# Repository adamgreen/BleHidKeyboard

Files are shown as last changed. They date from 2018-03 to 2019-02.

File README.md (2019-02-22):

# BLE HID Keyboard
A project to convert a [Perixx PERIDUO-307B USB wired keyboard](https://www.amazon.com/Perixx-PERIBOARD-407B-Mini-Keyboard-Dimension/dp/B0053O9ZNQ/) to wireless Bluetooth Low Energy (BLE). The conversion is accomplished by replacing the original PCB with the one documented here which uses a [Nordic nRF51422](https://www.nordicsemi.com/eng/Products/ANT/nRF51422) BLE capable ARM Cortex-M0 microcontroller. This repository includes the Eagle CAD PCB design files and firmware source code.

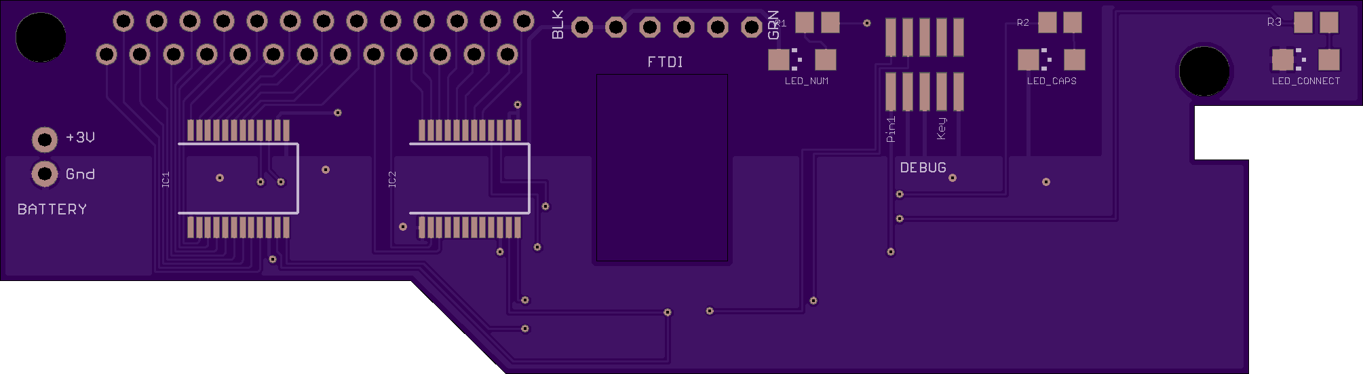
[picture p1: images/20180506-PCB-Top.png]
OSHPark rendering of PCB Top


## Bill of Materials
Description | Quantity | Part Number(s)
------------|----------|---------------
[Perixx PERIDUO-307B USB wired keyboard](https://www.amazon.com/Perixx-PERIBOARD-407B-Mini-Keyboard-Dimension/dp/B0053O9ZNQ/) | 1 |
[SODIAL 3W LED Mini Pen Torch Flashlight 2xAAA](https://www.amazon.com/gp/product/B01J58ZHOG) | 1 |
[1.2kΩ Resistor - 0805](https://www.adafruit.com/product/441) | 3 | R1, R2, R3
[Microchip MCP23018 I2C I/O Expander](https://www.digikey.com/product-detail/en/microchip-technology/MCP23018-E-SS/MCP23018-E-SS-ND/1999506) | 2 | IC1, IC2
[Samtec 2x5 SMT Micro Header](https://www.digikey.com/product-detail/en/FTSH-105-01-L-DV-K/SAM8799-ND/1875039) | 1 | JP1
[Dynastream N5150M5CD - nRF51422 Module](https://www.digikey.com/products/en?keywords=N5150M5CD) | 1 | U1
[Green SMT LED](https://www.digikey.com/product-detail/en/kingbright/APTD3216LCGCK/754-2049-1-ND/7043101) | 3 | LED_CAPS, LED_CONNECT, LED_NUM LED

It also requires a 2x13 ribbon cable connector harvested from the original PCB using a [Chip Quick SMD Removal Kit](https://www.adafruit.com/product/2660).

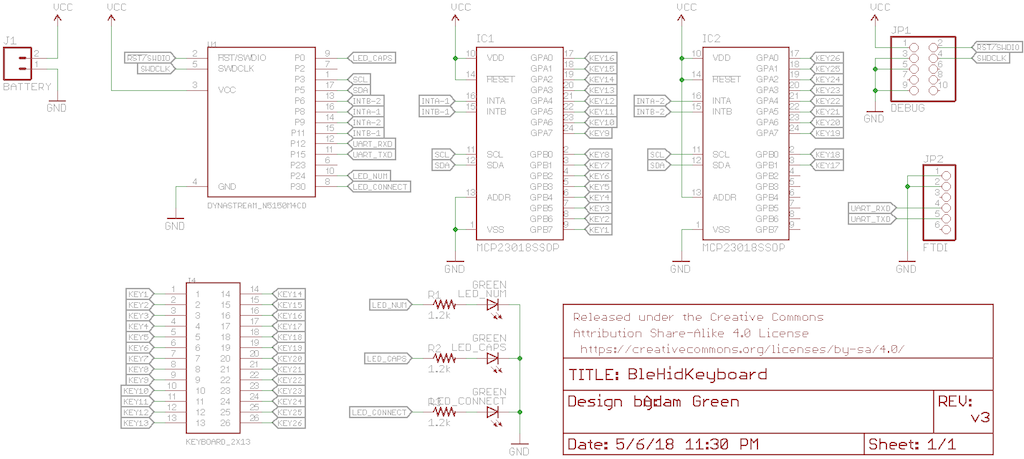
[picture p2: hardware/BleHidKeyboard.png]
Schematic


## Firmware Build
I have only tested the build on macOS but it will probably work on other Posix operating systems too.

**Note:** Building the firmware and deploying it to the nRF51 requires the **mergehex** and **nrfjprog** tools. The archive for your OS can be downloaded from the _Downloads_ tab of the [nRF51422 product page](https://www.nordicsemi.com/eng/Products/Bluetooth-low-energy/nRF51422). You will also need a SEGGER J-Link JTAG/SWD Debugger. If your projects are of a non-commercial nature, you can use this [low cost module available from Adafruit](https://www.adafruit.com/product/3571).

* ```make sdk``` will download and install the required Nordic SDK. This should only need to be done once.
* ```make flash_softdevice``` will install the required Nordic SoftDevice on the nRF51422 microcontroller using the J-Link debugger. This will typically only need to be done once for each microcontroller.
* ```make all``` will build the keyboard firmware.
* ```make flash```will build the keyboard firmware and deploy it using the J-Link debugger.
* ```make generate_patches``` can be used to generate diffs for any files that you have modified in the [config/ subfolder](https://github.com/adamgreen/BleHidKeyboard/tree/master/firmware/config) so that you can commit and share them via git.

## Photos
**Perixx PERIDUO-307B USB Wired Keyboard**<br>
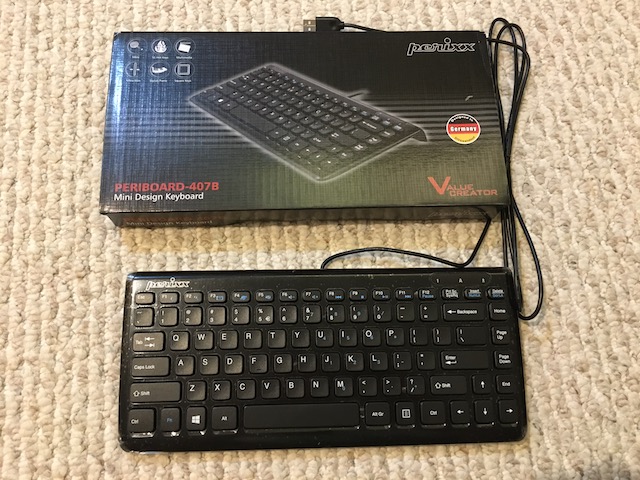
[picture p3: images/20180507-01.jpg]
Keyboard
<br>

**Inside of Keyboard with Original PCB**<br>
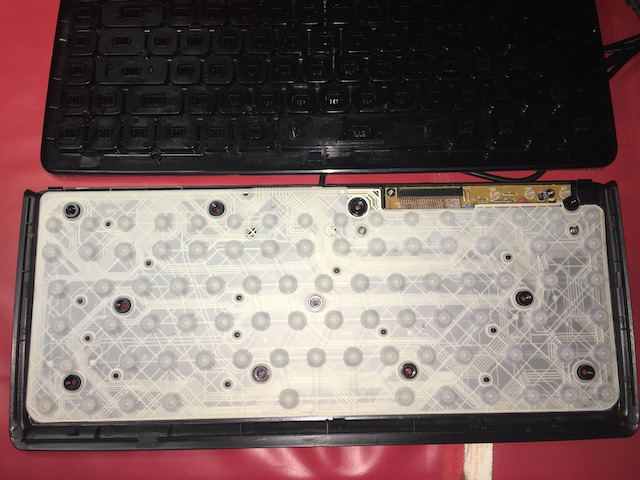
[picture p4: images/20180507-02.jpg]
Original PCB
<br>

**Inside of Keyboard with New BLE PCB**<br>
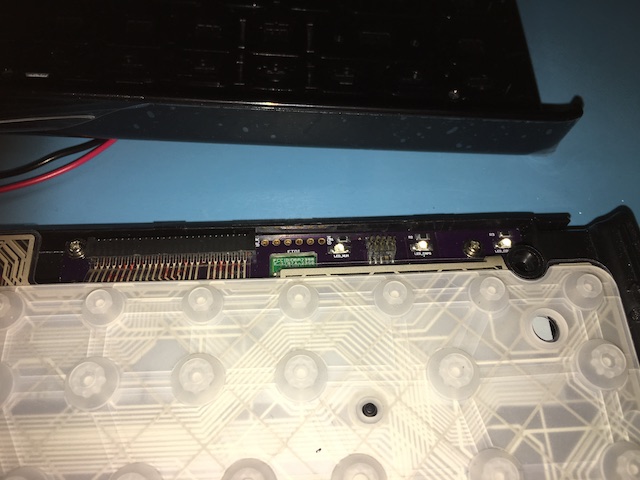
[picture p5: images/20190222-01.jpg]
New PCB From Top
<br>

**Peeking Under Membrane at New BLE PCB**<br>
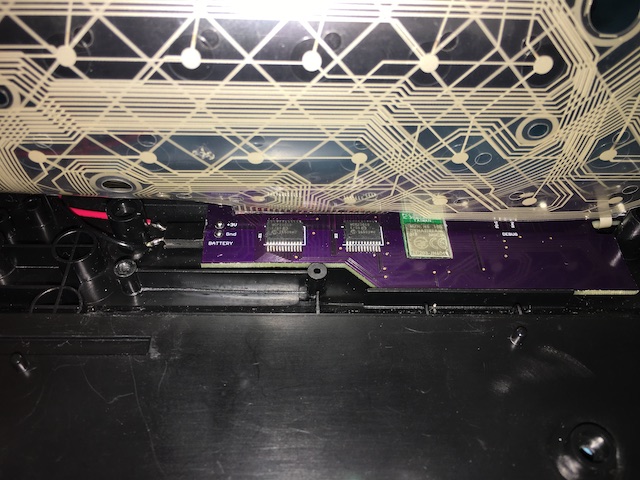
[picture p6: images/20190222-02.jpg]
New PCB Looking Under Membrane
<br>

**Inside of Keyboard After Modifications**<br>
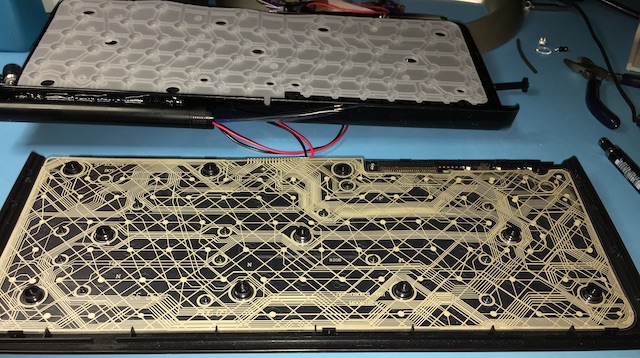
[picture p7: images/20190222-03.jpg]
Inside of Keyboard
<br>

**Keyboard with 2xAAA Torchlight as Battery Pack**<br>
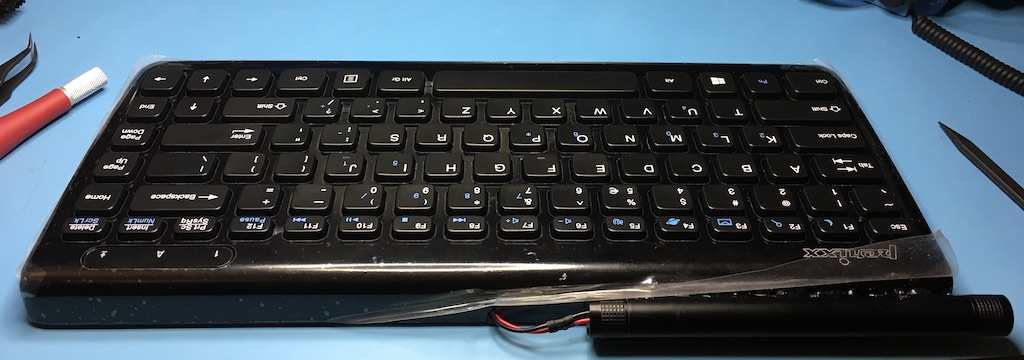
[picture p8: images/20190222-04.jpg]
Full Keyboard
<br>

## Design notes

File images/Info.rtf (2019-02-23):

Sleep: <Fn> + <F1>
Wakeup: <Space>
Forget Devices: Press <Delete> during power on

Scroll Lock LED
Blinking: Waiting to connect to device
Solid: Connected to device
Off: Sleeping or powered off

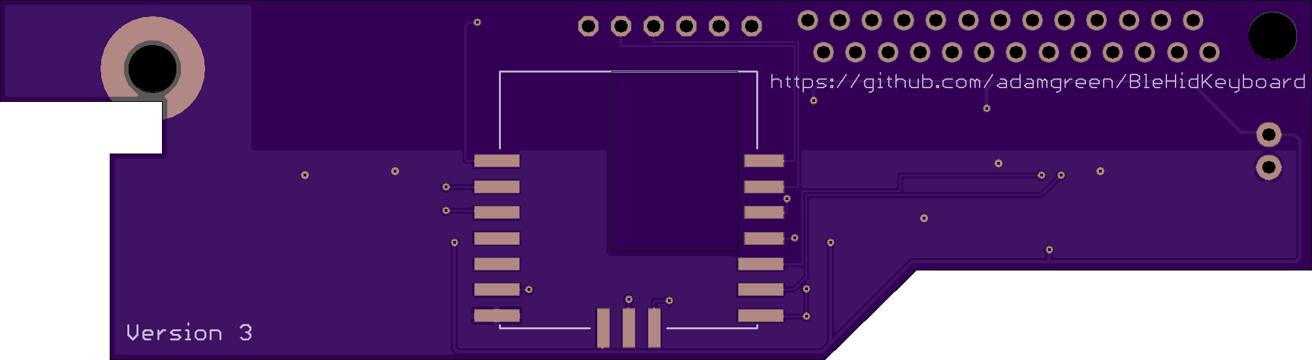
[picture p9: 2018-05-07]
images/20180506-PCB-Bottom.png

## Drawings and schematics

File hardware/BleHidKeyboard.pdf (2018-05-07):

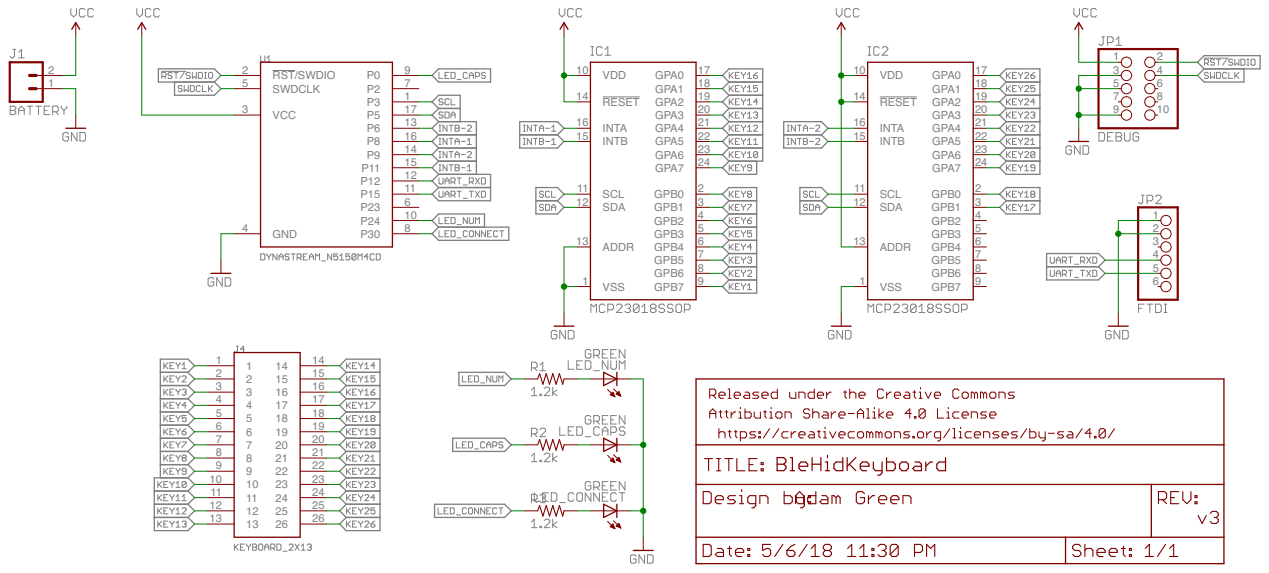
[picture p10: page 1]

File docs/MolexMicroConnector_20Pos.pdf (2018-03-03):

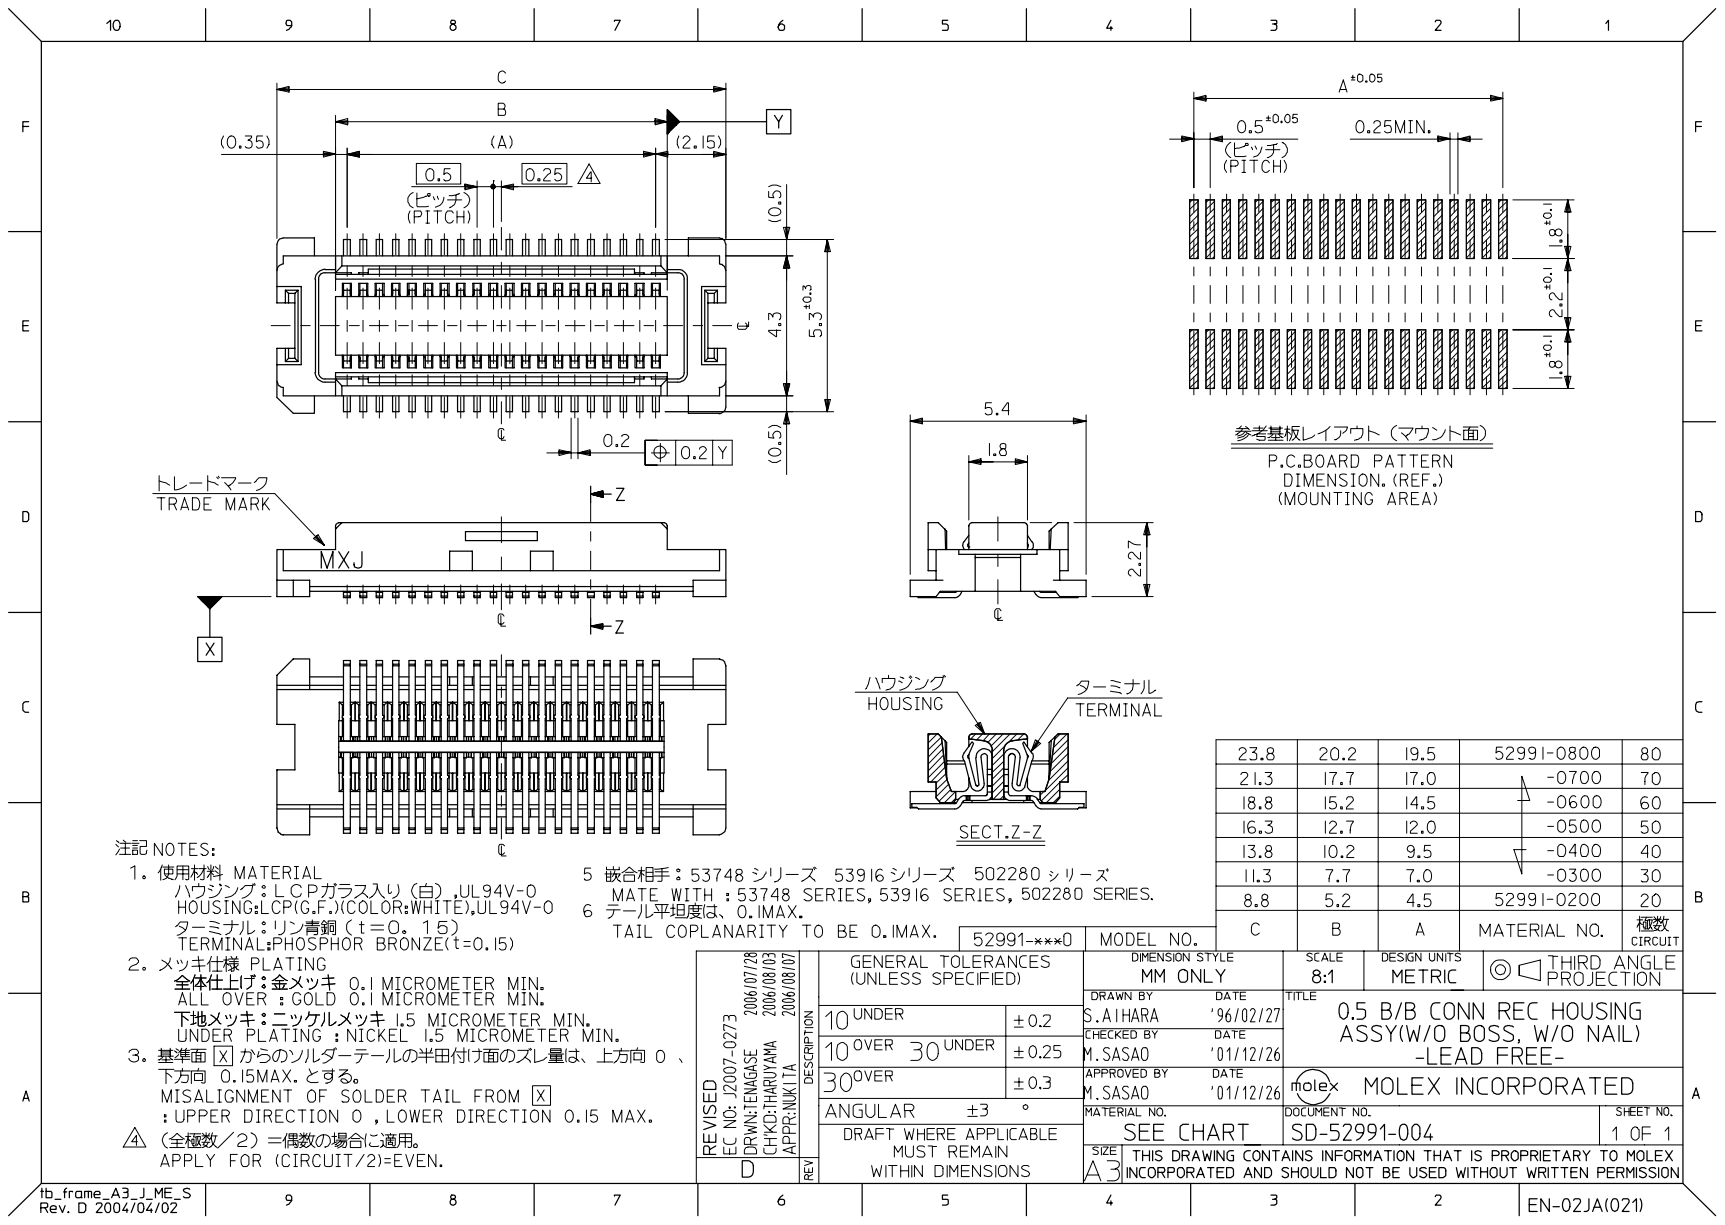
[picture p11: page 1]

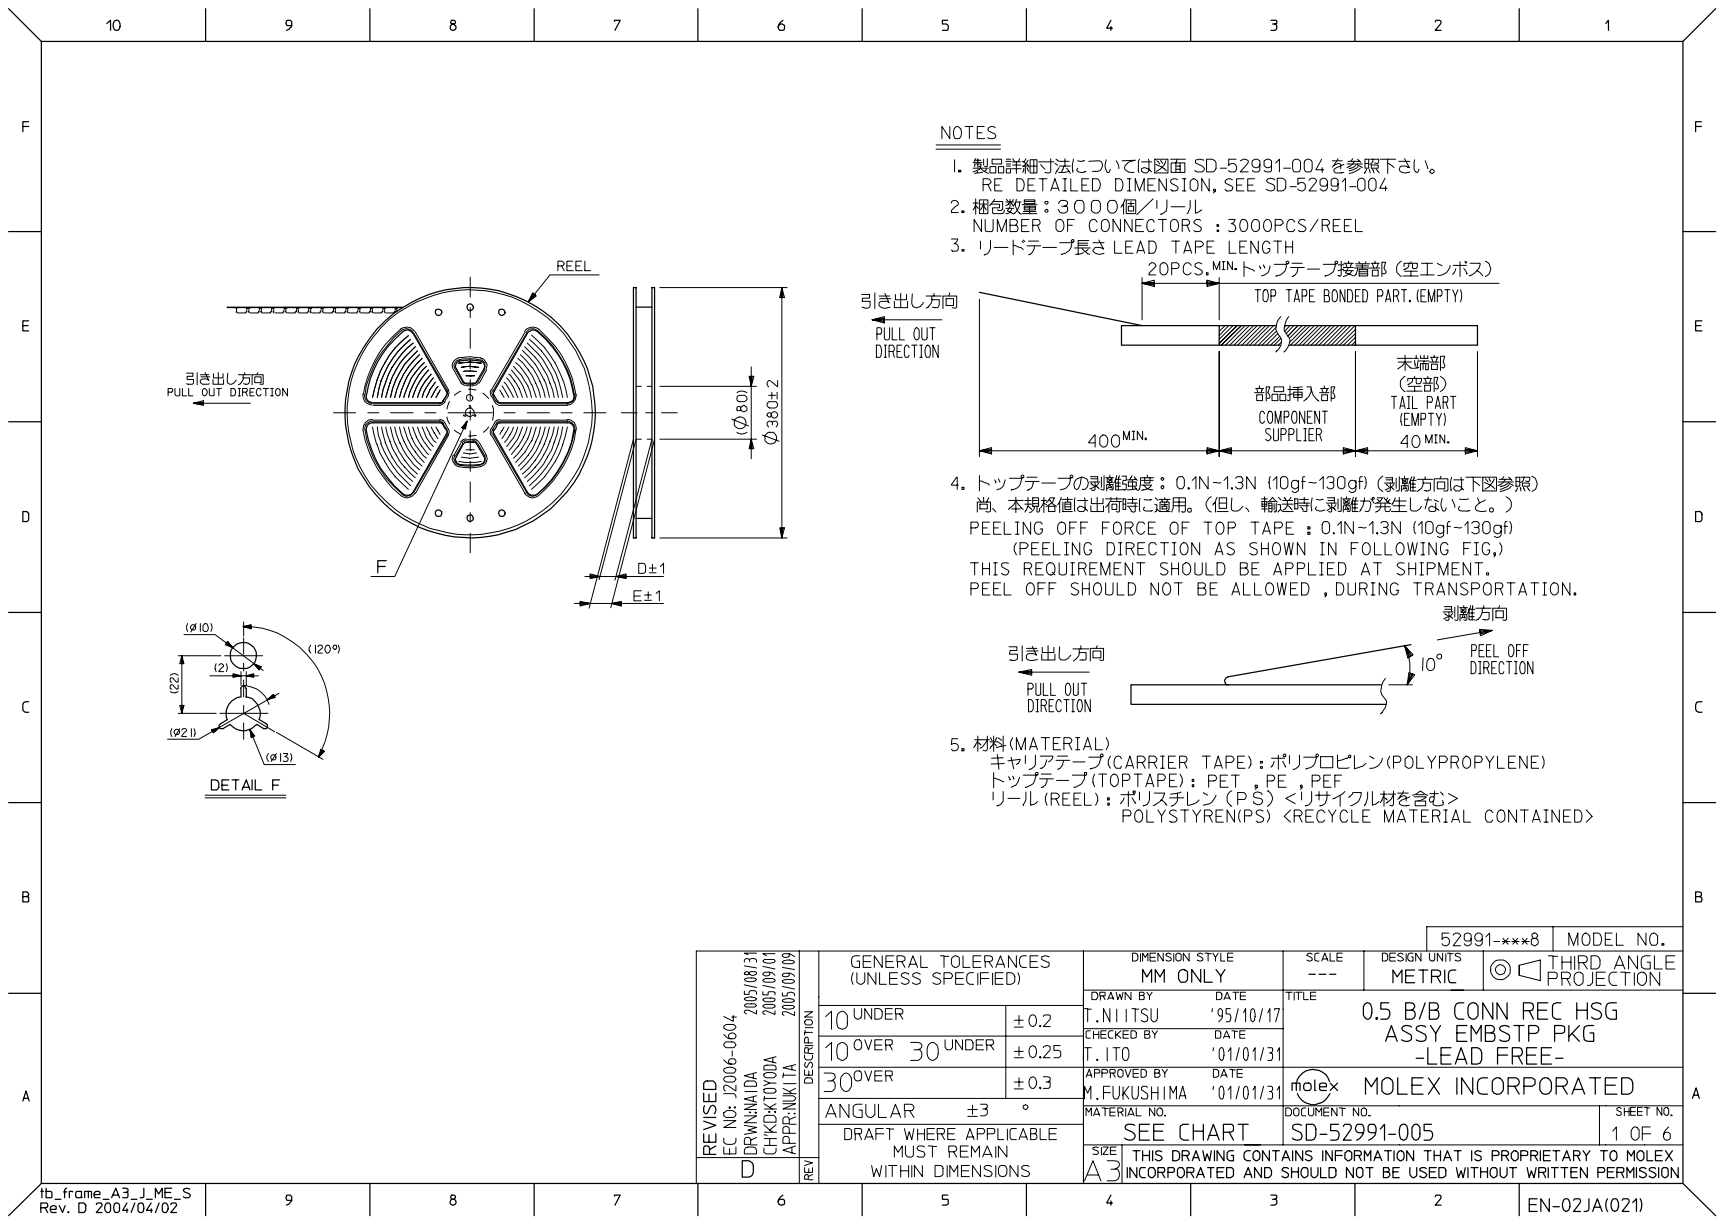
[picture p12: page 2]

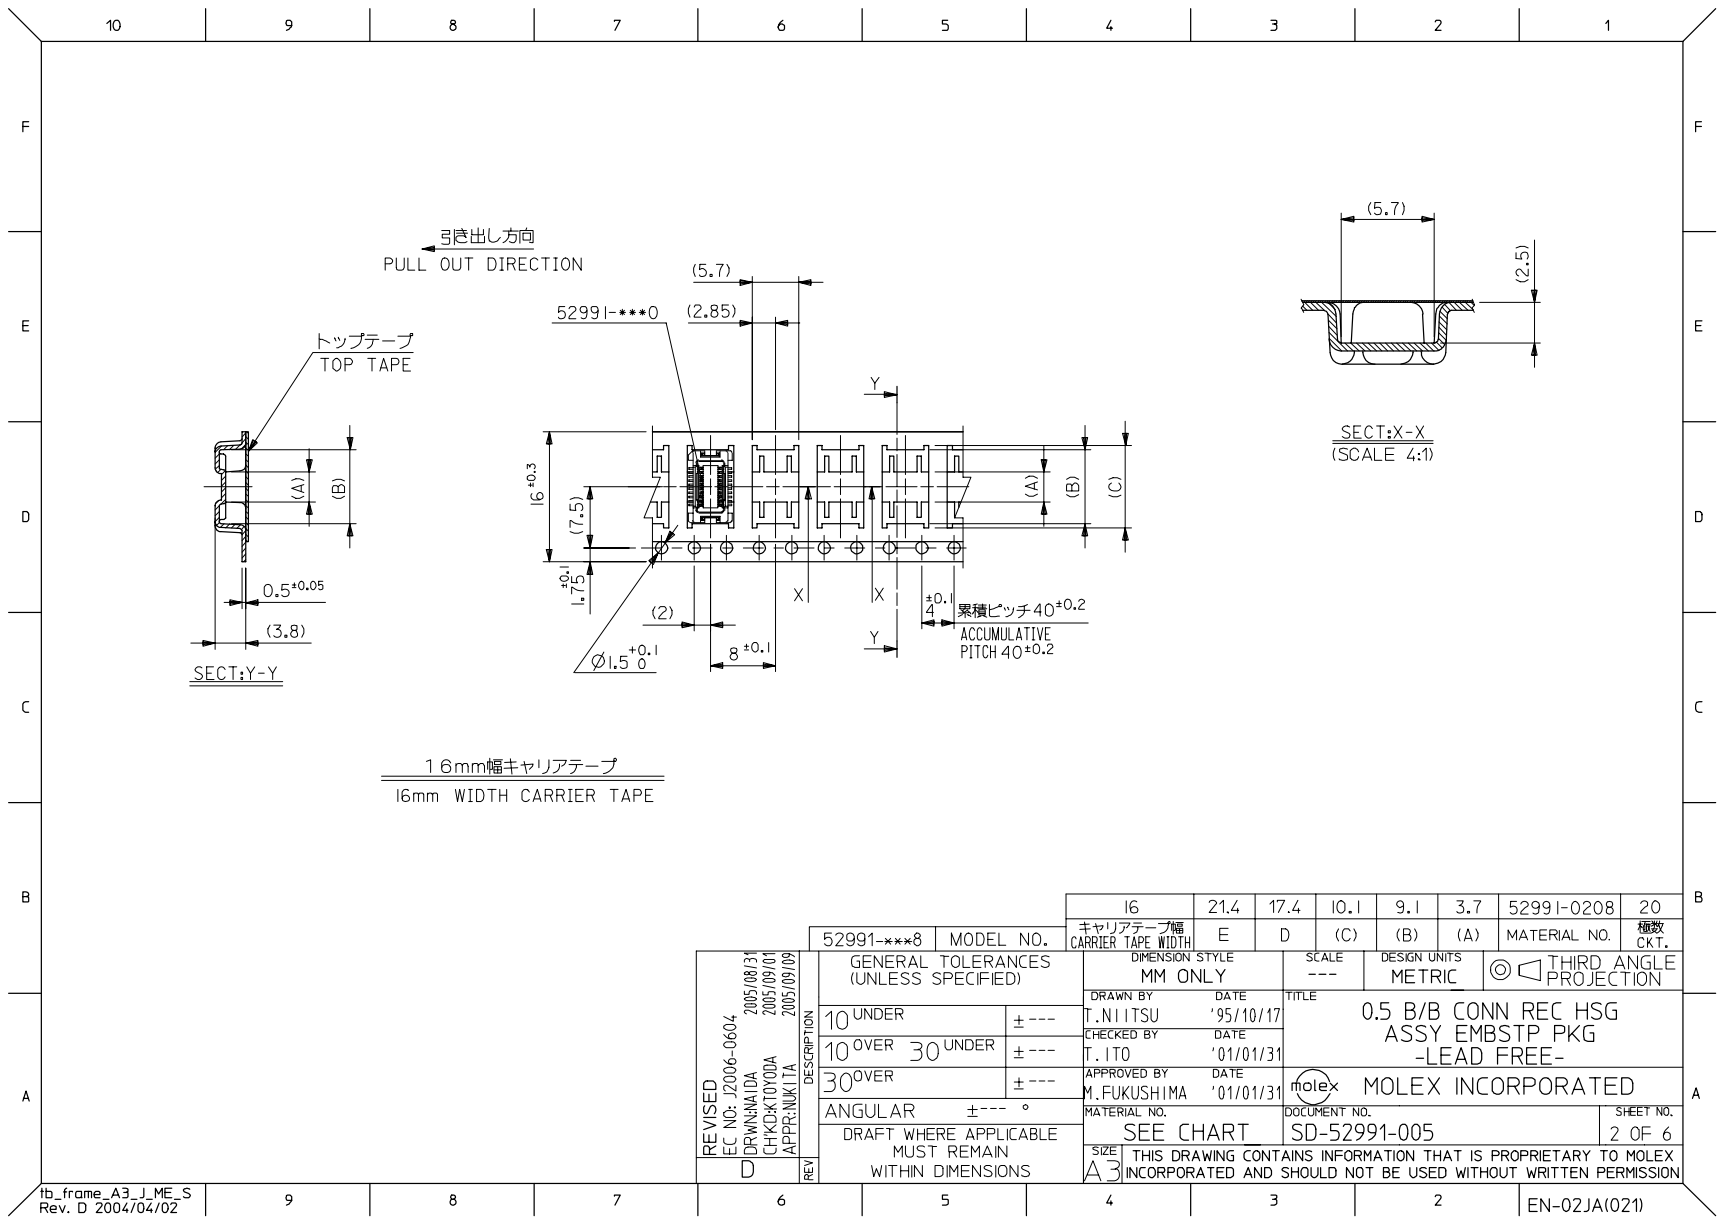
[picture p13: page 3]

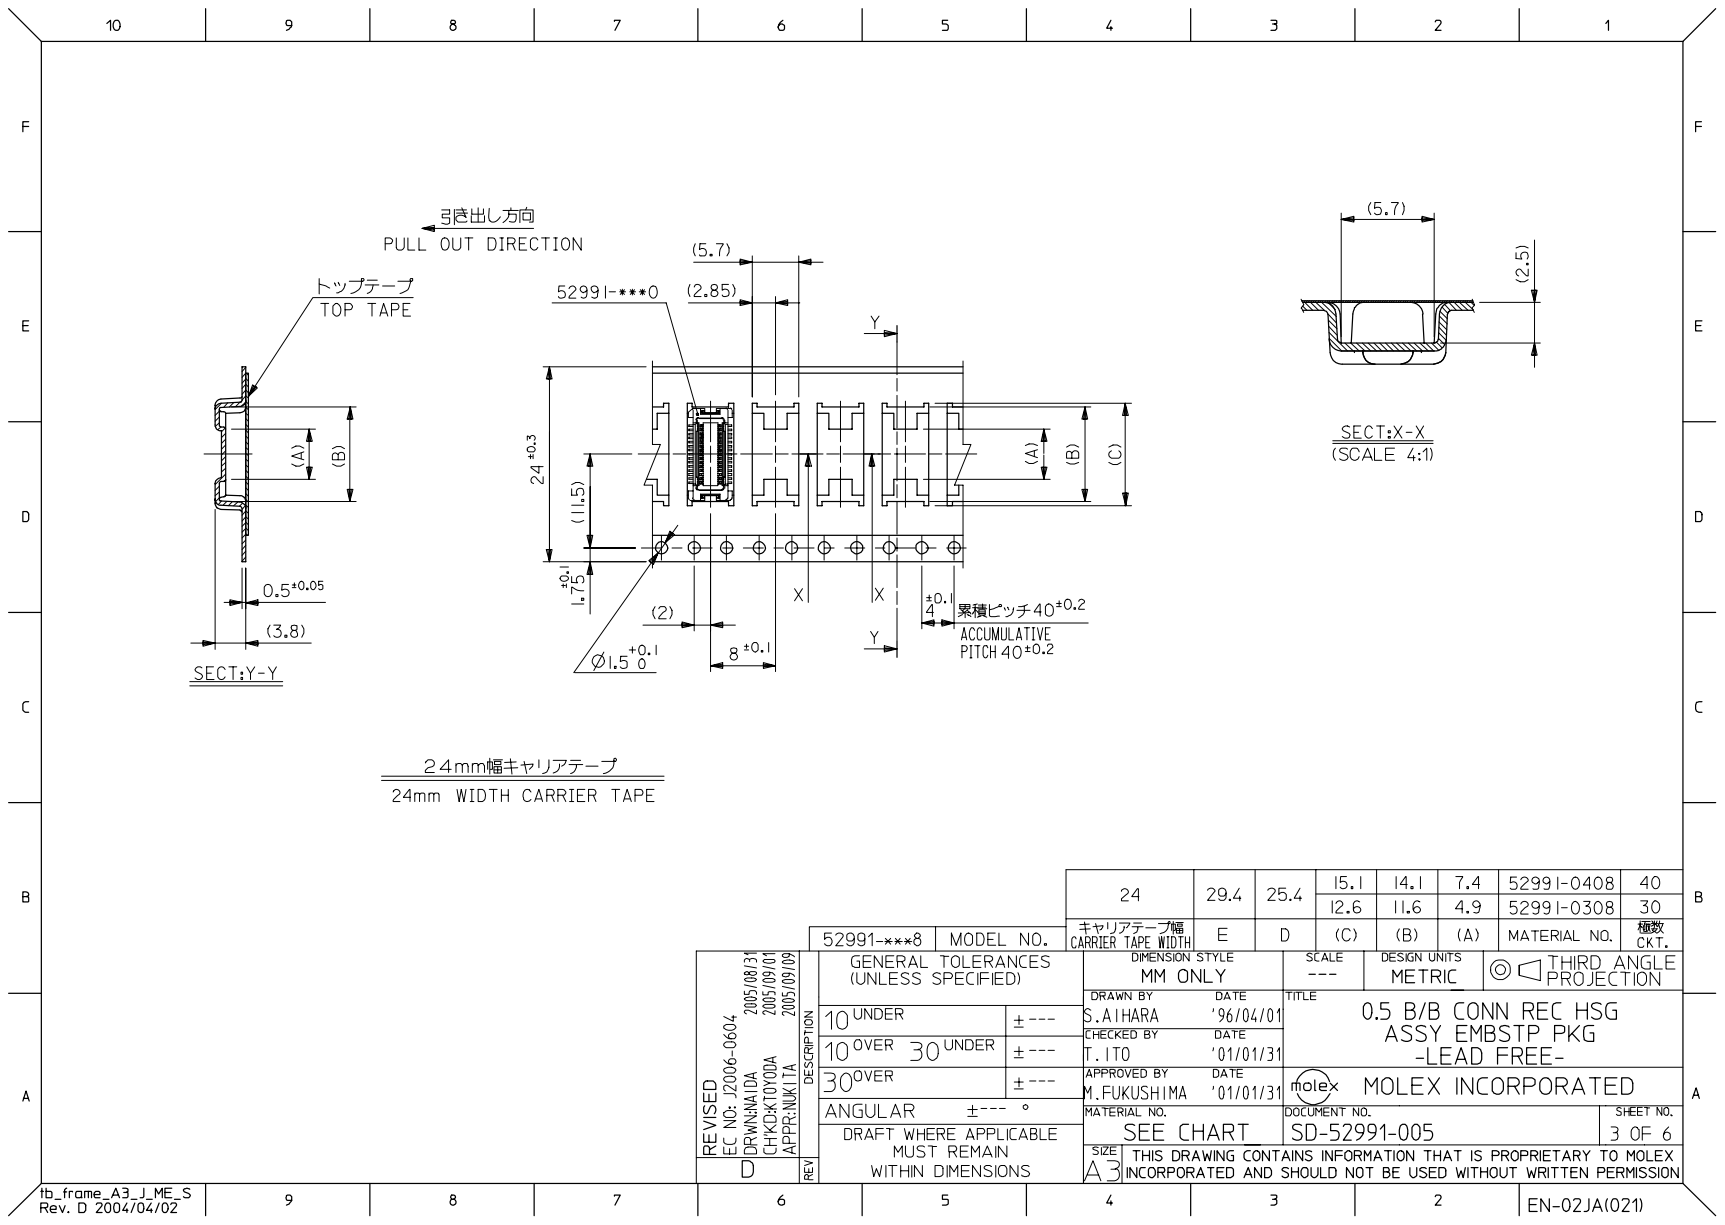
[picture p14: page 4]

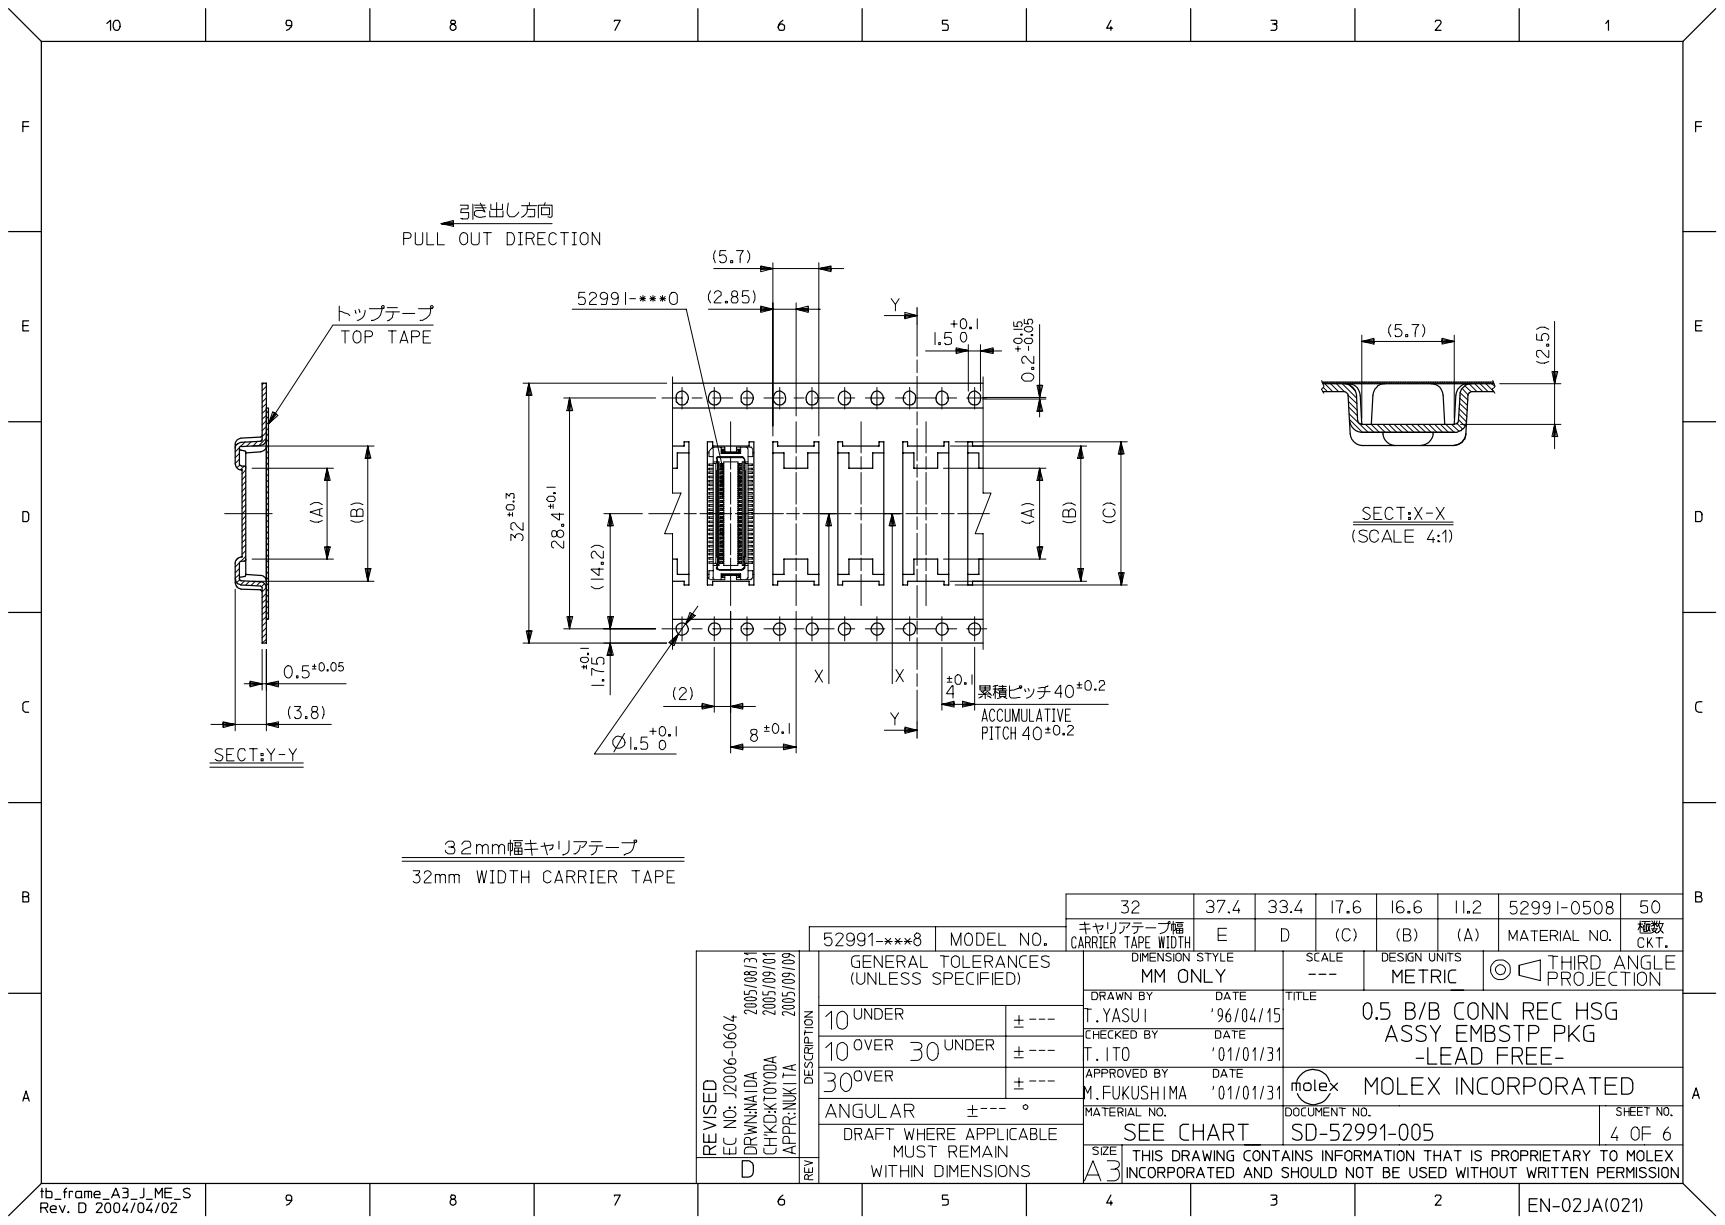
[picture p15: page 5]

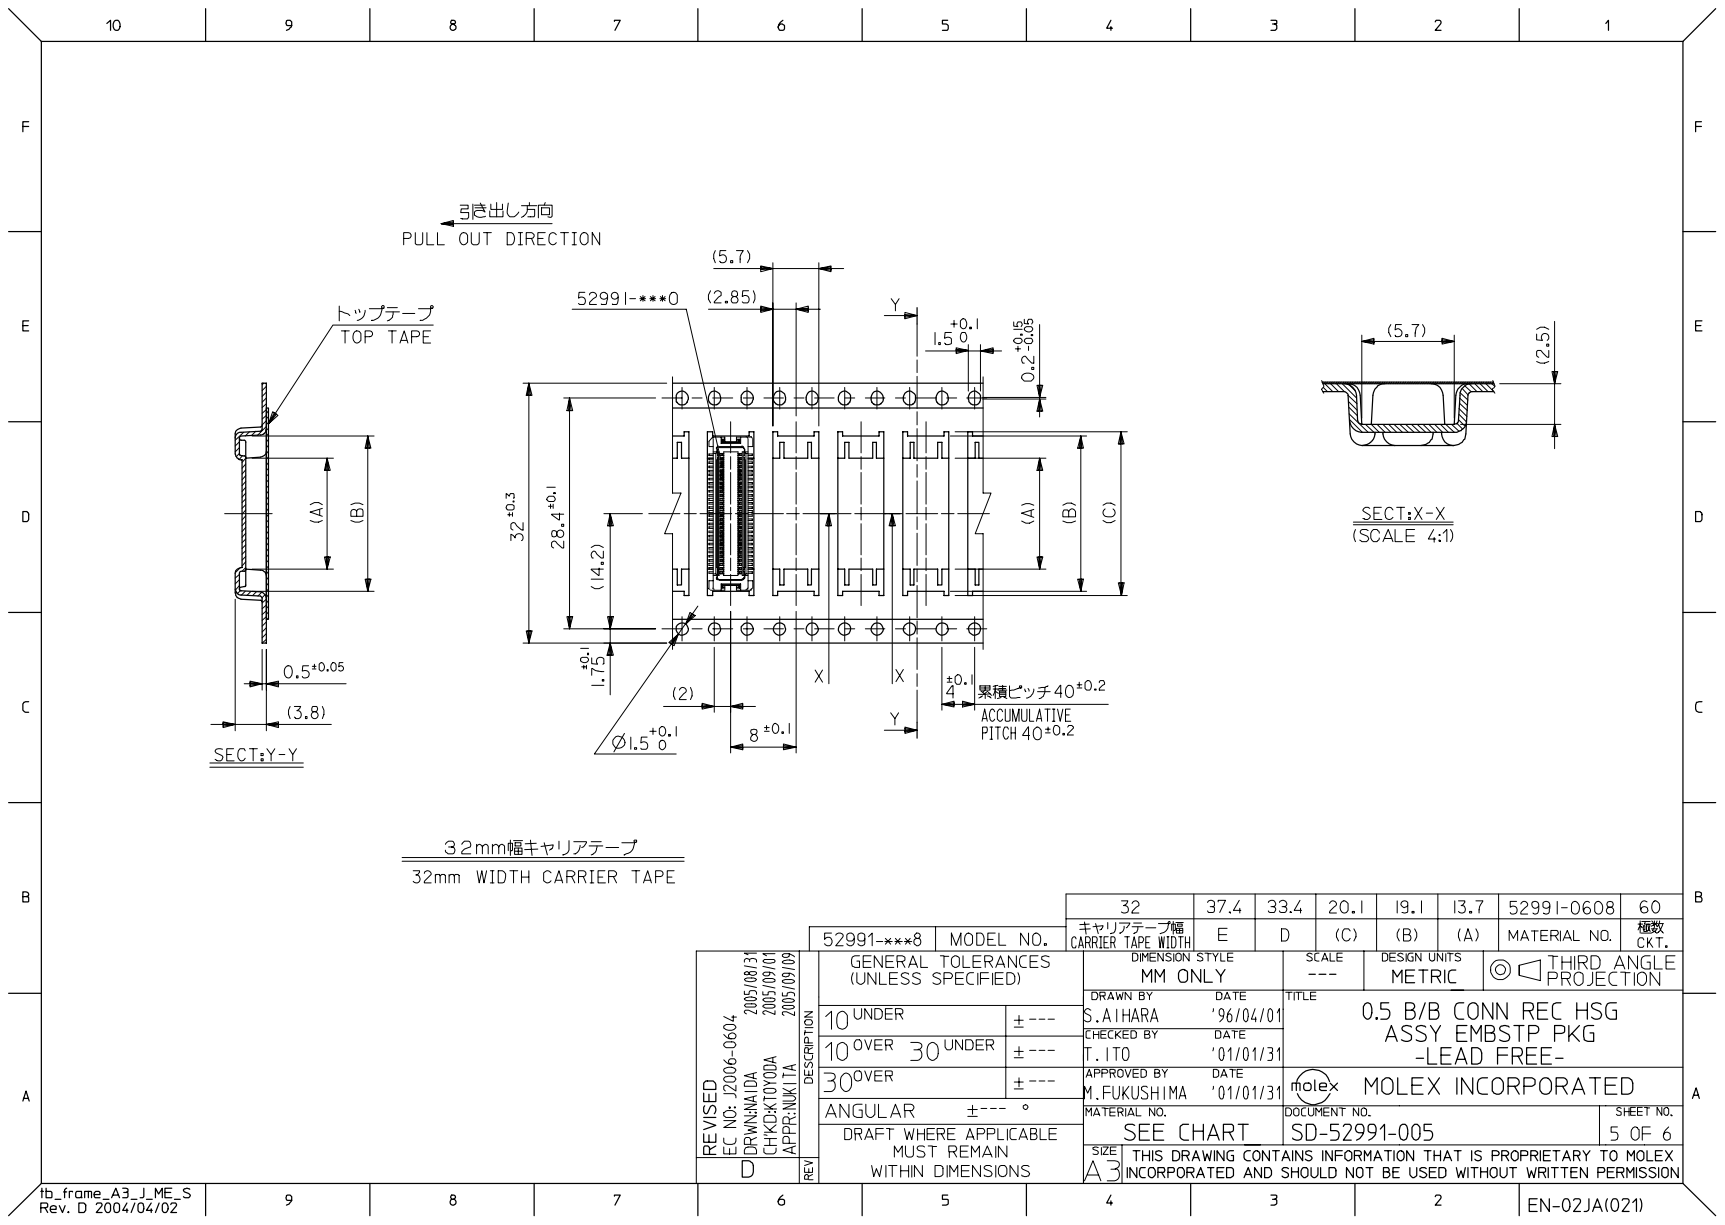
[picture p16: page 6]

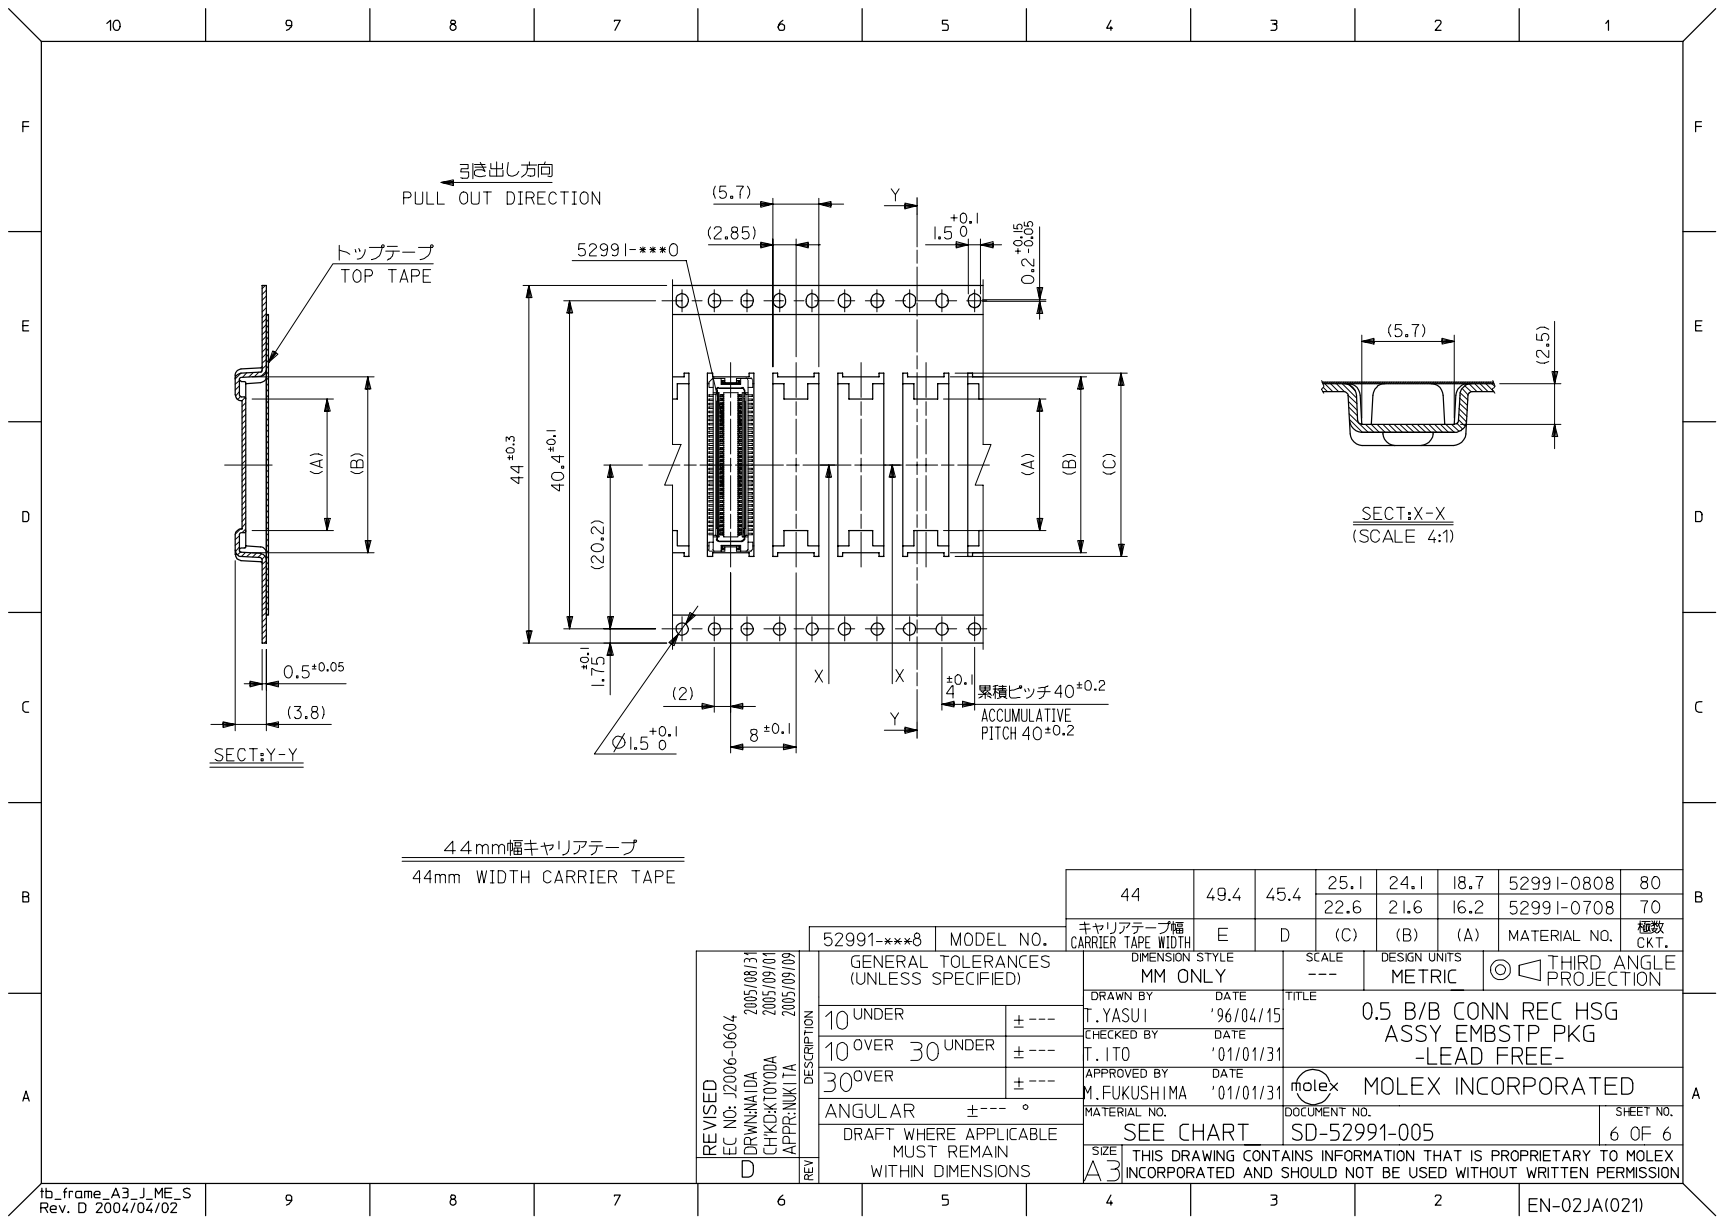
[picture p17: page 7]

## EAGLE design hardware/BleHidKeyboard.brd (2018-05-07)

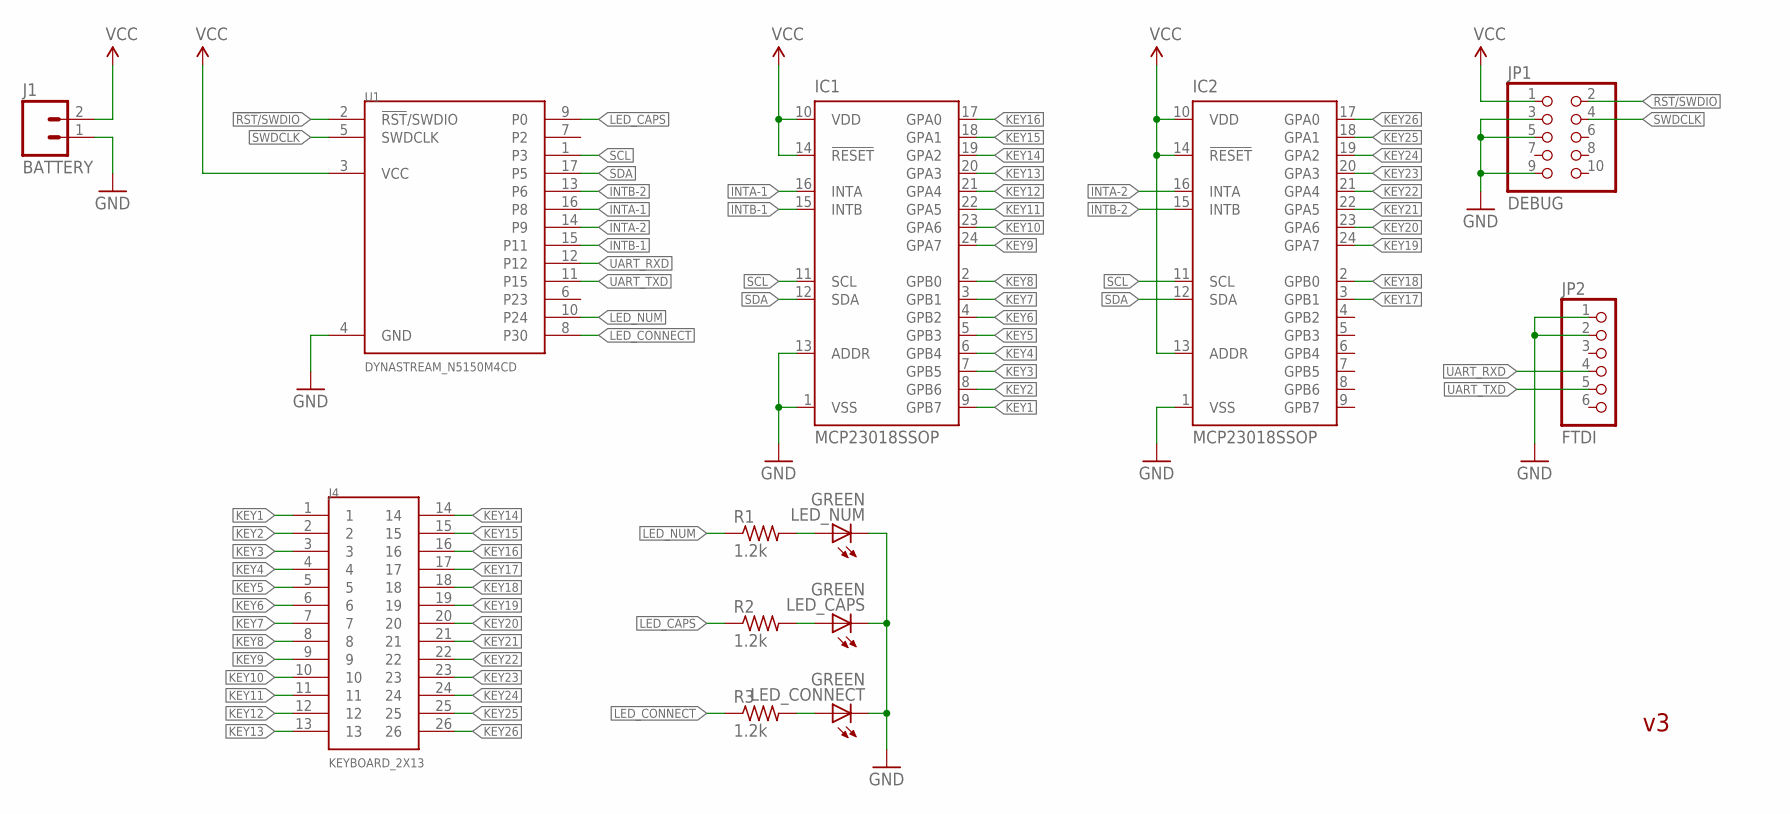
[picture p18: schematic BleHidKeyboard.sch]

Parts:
IC1, IC2: MCP23018SSOP; SSOP24
J1: BATTERY; 1X02_NO_SILK
J4: KEYBOARD_2X13
JP1: DEBUG; FTSH-105
JP2: FTDI; 1X06-CLEAN
LED_CAPS: GREEN; CHIPLED_1206
LED_CONNECT: GREEN; CHIPLED_1206
LED_NUM: GREEN; CHIPLED_1206
R1, R2, R3: 1.2k; R0805
U1: DYNASTREAM_N5150M4CD; N5150M4CD

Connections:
!RST/!SWDIO: JP1.2, U1.2 (!RST!/SWDIO)
GND: IC1.1 (VSS), IC1.13 (ADDR), IC2.1 (VSS), J1.1, JP1.3, JP1.5, JP1.9, JP2.1, JP2.2, LED_CAPS.C, LED_CONNECT.C, LED_NUM.C, U1.4 (GND)
INTA-1: IC1.16 (INTA), U1.16 (P8)
INTA-2: IC2.16 (INTA), U1.14 (P9)
INTB-1: IC1.15 (INTB), U1.15 (P11)
INTB-2: IC2.15 (INTB), U1.13 (P6)
KEY1: IC1.9 (GPB7), J4.1
KEY2: IC1.8 (GPB6), J4.2
KEY3: IC1.7 (GPB5), J4.3
KEY4: IC1.6 (GPB4), J4.4
KEY5: IC1.5 (GPB3), J4.5
KEY6: IC1.4 (GPB2), J4.6
KEY7: IC1.3 (GPB1), J4.7
KEY8: IC1.2 (GPB0), J4.8
KEY9: IC1.24 (GPA7), J4.9
KEY10: IC1.23 (GPA6), J4.10
KEY11: IC1.22 (GPA5), J4.11
KEY12: IC1.21 (GPA4), J4.12
KEY13: IC1.20 (GPA3), J4.13
KEY14: IC1.19 (GPA2), J4.14
KEY15: IC1.18 (GPA1), J4.15
KEY16: IC1.17 (GPA0), J4.16
KEY17: IC2.3 (GPB1), J4.17
KEY18: IC2.2 (GPB0), J4.18
KEY19: IC2.24 (GPA7), J4.19
KEY20: IC2.23 (GPA6), J4.20
KEY21: IC2.22 (GPA5), J4.21
KEY22: IC2.21 (GPA4), J4.22
KEY23: IC2.20 (GPA3), J4.23
KEY24: IC2.19 (GPA2), J4.24
KEY25: IC2.18 (GPA1), J4.25
KEY26: IC2.17 (GPA0), J4.26
LED_CAPS: R2.1, U1.9 (P0)
LED_CONNECT: R3.1, U1.8 (P30)
LED_NUM: R1.1, U1.10 (P24)
unnamed: LED_NUM.A, R1.2
unnamed: LED_CAPS.A, R2.2
unnamed: LED_CONNECT.A, R3.2
SCL: IC1.11 (SCL), IC2.11 (SCL), U1.1 (P3)
SDA: IC1.12 (SDA), IC2.12 (SDA), U1.17 (P5)
SWDCLK: JP1.4, U1.5 (SWDCLK)
UART_RXD: JP2.4, U1.12
UART_TXD: JP2.5, U1.11 (P15)
VCC: IC1.10 (VDD), IC1.14 (!RESET), IC2.10 (VDD), IC2.13 (ADDR), IC2.14 (!RESET), J1.2, JP1.1, U1.3 (VCC)

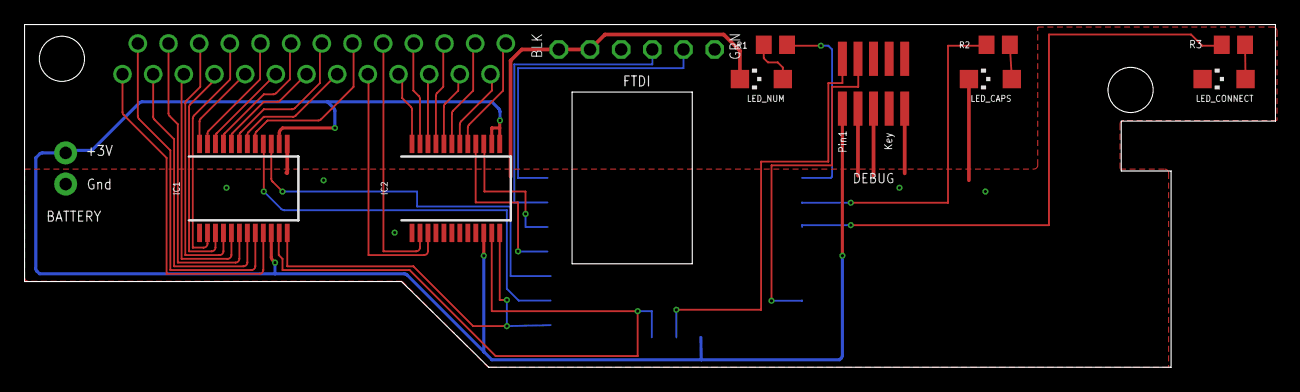
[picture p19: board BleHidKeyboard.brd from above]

Board: 2 copper layers, 102.0 x 27.9 mm, 13 parts (0 on the bottom side), 44 nets.

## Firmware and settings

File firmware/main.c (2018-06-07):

/*  Copyright (C) 2018  Adam Green (https://github.com/adamgreen)

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
    This program is distributed in the hope that it will be useful,
    but WITHOUT ANY WARRANTY; without even the implied warranty of
    MERCHANTABILITY or FITNESS FOR A PARTICULAR PURPOSE.  See the
    GNU General Public License for more details.
*/
/*
    Wireless keyboard firmware.
    This firmware is essentially a combination of 2 main features:
    * Wireless connectivity to PC via Bluetooth Low Energy HID protocol. This allows it to work on iOS devices.
    * Remapping of alpha keys so that they can be arranged in ABC order instead of the usual QWERTY.

    The BLE code in this project originated from Nordic Semiconductor's BLE HID Keyboard Sample.
*/
#include <stdint.h>
#include <string.h>
#include <nordic_common.h>
#include <nrf.h>
#include <nrf_assert.h>
#include <app_error.h>
#include <nrf_gpio.h>
#include <ble.h>
#include <ble_hci.h>
#include <ble_srv_common.h>
#include <ble_advertising.h>
#include <ble_advdata.h>
#include <ble_hids.h>
#include <ble_bas.h>
#include <ble_dis.h>
#include <ble_conn_params.h>
#include <bsp.h>
#include <app_scheduler.h>
#include <softdevice_handler_appsh.h>
#include <app_timer_appsh.h>
#include <device_manager.h>
#include <app_button.h>
#include <pstorage.h>
#include <app_trace.h>
#include <nrf_drv_gpiote.h>
#include <app_uart.h>
#include <nrf_adc.h>
#include "KeyboardMatrix.h"
#include "MCP23018.h"
#include "nrf_drv_timer.h"


// nRF51 pins connected to the I2C pins on the MCP23018 I/O expanders used with the keyboard matrix.
#define KEYBOARD_SCL_PIN                3
#define KEYBOARD_SDA_PIN                5

// The INTA & INTB pins for each of the MCP23018 devices.
#define KEYBOARD_INTA1_PIN              8
#define KEYBOARD_INTB1_PIN              11
#define KEYBOARD_INTA2_PIN              9
#define KEYBOARD_INTB2_PIN              6

// There are two MCP23018 16-bit I/O expanders used to connect to all of the columns and rows of the keyboard matrix.
// The following defines provide the I2C addresss of these two MCP23018 expanders.
#define KEYBOARD_MCP23018_1_I2C_ADDRESS 0x20
#define KEYBOARD_MCP23018_2_I2C_ADDRESS 0x27

// Configuration options for the interrupt driven UART driver.
#define UART_TX_PIN      15
#define UART_RX_PIN      12
// CTS & RTS not actually used in this implementation.
#define UART_CTS_PIN     0xFF
#define UART_RTS_PIN     0xFF
#define UART_TX_BUF_SIZE 256
#define UART_RX_BUF_SIZE 1

// nRF51 pins used for caps and num lock LEDs.
#define CAPS_LOCK_PIN   0
#define NUM_LOCK_PIN    24

// Set to non-zero value to dump BLE HID reports.
#define DEBUG_SHOW_HID_REPORT       0

// Set to non-zero value if we want to remap keyboard to be special alphabetical order keyboard.
#define KEYBOARD_IS_SPECIAL_ABC     1

// BLE HID is based on USB HID. The keyboard communicates with 8-byte input reports and 1-byte output report.
// Version number of base USB HID Specification implemented by this application.
#define BASE_USB_HID_SPEC_VERSION        0x0101
// Index of Output Report.
#define OUTPUT_REPORT_INDEX              0
// Maximum length of Output Report.
#define OUTPUT_REPORT_MAX_LEN            sizeof(HidKeyboardOutputReport)
// Id of reference to Keyboard Output Report.
#define OUTPUT_REP_REF_ID                0
// Index of Input Report.
#define INPUT_REPORT_KEYS_INDEX          0
// Id of reference to Keyboard Input Report.
#define INPUT_REP_REF_ID                 0
// Maximum length of the Input Report characteristic.
#define INPUT_REPORT_KEYS_MAX_LEN        sizeof(HidKeyboardInputReport)


// Include or not the service_changed characteristic. 
// If not enabled, the server's database cannot be changed for the lifetime of the device.
#define IS_SRVC_CHANGED_CHARACT_PRESENT  0                                              

// Name of device. Will be included in the advertising data.
#define DEVICE_NAME                      "Pat's Keyboard"
// Manufacturer. Will be passed to Device Information Service.
#define MANUFACTURER_NAME                "PinkyDevelopment"
// Product/Vendor IDs reported by Device Information Service.
#define PNP_ID_VENDOR_ID_SOURCE          0x02
#define PNP_ID_VENDOR_ID                 0x1915
#define PNP_ID_PRODUCT_ID                0xEEEE
#define PNP_ID_PRODUCT_VERSION           0x0001

// RTC1 low speed (32.768kHz) based application timer.
#define APP_TIMER_PRESCALER              0
#define APP_TIMER_OP_QUEUE_SIZE          4

// Update battery level measurement every minute.
#define BATTERY_LEVEL_MEAS_INTERVAL      APP_TIMER_TICKS(60000, APP_TIMER_PRESCALER)

// Turn NumLock LED off after 0.25 seconds when digit for pass key is pressed. Also used for debouncing these key presses.
#define LED_BLINK_INTERVAL              APP_TIMER_TICKS(250, APP_TIMER_PRESCALER)

// Fast advertising interval (in units of 0.625 ms. This value corresponds to 25 ms.).
#define APP_ADV_FAST_INTERVAL            0x0028                                         
// Slow advertising interval (in units of 0.625 ms. This value corrsponds to 2 seconds).
#define APP_ADV_SLOW_INTERVAL            0x0C80
// The duration of the fast advertising period (in seconds).
#define APP_ADV_FAST_TIMEOUT             30
// The duration of the slow advertising period (in seconds).
#define APP_ADV_SLOW_TIMEOUT             180

// Based on a really fast typing rate of 1000 characters per minute = 16 characters per second.
// A period of 62.6 milliseconds for 16Hz.
// Minimum connection interval (62.6 ms).
#define MIN_CONN_INTERVAL                MSEC_TO_UNITS(62.6, UNIT_1_25_MS)
// Maximum connection interval (120 ms).
#define MAX_CONN_INTERVAL                MSEC_TO_UNITS(120, UNIT_1_25_MS)
// Slave latency.
#define SLAVE_LATENCY                    5
// Connection supervisory timeout (2 seconds).
#define CONN_SUP_TIMEOUT                 MSEC_TO_UNITS(2000, UNIT_10_MS)

// Time from initiating event (connect or start of notification) to first time sd_ble_gap_conn_param_update is called (5 seconds).
#define FIRST_CONN_PARAMS_UPDATE_DELAY   APP_TIMER_TICKS(5000, APP_TIMER_PRESCALER)     
// Time between each call to sd_ble_gap_conn_param_update after the first call (30 seconds).
#define NEXT_CONN_PARAMS_UPDATE_DELAY    APP_TIMER_TICKS(30000, APP_TIMER_PRESCALER)
// Number of attempts before giving up the connection parameter negotiation.
#define MAX_CONN_PARAMS_UPDATE_COUNT     3

// Perform bonding.
#define SEC_PARAM_BOND                   1                                              
// Man In The Middle protection IS required.
#define SEC_PARAM_MITM                   1
// This device is only capable of keyboard input (it has no display, etc).
#define SEC_PARAM_IO_CAPABILITIES        BLE_GAP_IO_CAPS_KEYBOARD_ONLY
// Out Of Band data not available.
#define SEC_PARAM_OOB                    0
// Minimum encryption key size.
#define SEC_PARAM_MIN_KEY_SIZE           7
// Maximum encryption key size.
#define SEC_PARAM_MAX_KEY_SIZE           16                                             

// Reply when unsupported features are requested.
#define APP_FEATURE_NOT_SUPPORTED       BLE_GATT_STATUS_ATTERR_APP_BEGIN + 2            

// Value used as error code on stack dump, can be used to identify stack location on stack unwind.
#define DEAD_BEEF                        0xDEADBEEF                                     

// Application Scheduler Settings.
#define SCHED_MAX_EVENT_DATA_SIZE        (MAX(APP_TIMER_SCHED_EVT_SIZE,BLE_STACK_HANDLER_SCHED_EVT_SIZE))
#define SCHED_QUEUE_SIZE                 10                                  



// BLE Advertising Modes.
typedef enum
{
    BLE_NO_ADV,               // No advertising running.
    BLE_DIRECTED_ADV,         // Direct advertising to the latest central.
    BLE_FAST_ADV_WHITELIST,   // Advertising with whitelist.
    BLE_FAST_ADV,             // Fast advertising running.
    BLE_SLOW_ADV,             // Slow advertising running.
    BLE_SLEEP,                // Go to system-off.
} ble_advertising_mode_t;


// Battery timer.
APP_TIMER_DEF(g_batteryTimerId);
// Timer for blinking NumLock LED when typing in pass key.
APP_TIMER_DEF(g_blinkTimerId);

// Structure used to identify the HID service.
static ble_hids_t                   g_hids;
// Structure used to identify the battery service.
static ble_bas_t                    g_bas;
// Handle of the current connection.
static uint16_t                     g_connHandle = BLE_CONN_HANDLE_INVALID;       
// Current protocol mode. Keyboard can run in standard HID mode or boot mode where it uses a fixed report format.
static bool                         g_inBootMode = false;
// Is the bonding process currently waiting for the pass key to be input and sent back to the central.
static bool                         g_waitingForPassKey = false;
// Buffer to be filled in with 6 digit pass key.
static uint8_t                      g_passKeyBuffer[6];
// Current index into g_passKeyBuffer.
static uint8_t                      g_passKeyBufferIndex = 0;

// Application identifier allocated by device manager.
static dm_application_instance_t    g_appHandle;
// Device reference handle to the current bonded central.
static dm_handle_t                  g_bondedPeerHandle;

// Advertise that this is a standard BLE HID device.
static ble_uuid_t                   g_advertisingUuids[] = {{BLE_UUID_HUMAN_INTERFACE_DEVICE_SERVICE, BLE_UUID_TYPE_BLE}};

// Object used to interact with the keyboard matrix.
static KeyboardMatrix               g_keyboardMatrix;


// Forward function declarations.
static void initUart(void);
static void handleUartEvent(app_uart_evt_t* pEvent);
static void initRtcTimers(void);
static void handleBatteryLevelTimerEvent(void* pContext);
static void keyboardTimerHandler(nrf_timer_event_t eventType, void* pvContext);
static void handleBlinkTimerEvent(void* pContext);
static void initNumCapsLEDs();
static void initBspLeds();
static void handleBspEvent(bsp_event_t event);
static void enterSleepMode(void);
static void initBatteryLevelReads();
static void initBleStack(void);
static void handleBleEvent(ble_evt_t * pBleEvent);
static void handleBleEventForApplication(ble_evt_t * pBleEvent);
static void handleSystemEvent(uint32_t sysEvent);
static void initScheduler(void);
static void initDeviceManager(bool eraseBonds);
static uint32_t handleDeviceManagerEvent(dm_handle_t const* pHandle,
                                         dm_event_t const*  pEvent,
                                         ret_code_t         eventResult);
static void initGapParams(void);
static void initAdvertising(void);
static void handleAdvertisingEvent(ble_adv_evt_t bleAdvertisingEvent);
static void handleBleAdvertisingError(uint32_t errorCode);
static void initBleServices(void);
static void initDeviceInformationService(void);
static void initBatteryService(void);
static void initHidServiceForKeyboard(void);
static void handleHidEvent(ble_hids_t * p_hids, ble_hids_evt_t *p_evt);
static void handleHidOutputReportWrite(ble_hids_evt_t *p_evt);
static void updateKeyboardLeds(uint8_t hidLedBitmask);
static void handleServiceError(uint32_t errorCode);
static void initConnectionParams(void);
static void handleConnectionParamsError(uint32_t errorCode);
static void startRtcTimers(void);
static void sendInputReportHandler(HidKeyboardInputReport* pReportToSend, void* pvContext, bool sleepPressed);
static void enterLowPowerModeAndWakeOnEvent(void);



int main(void)
{
    bool     eraseBonds = false;
    uint32_t errorCode;

    initUart();
    initRtcTimers();
    errorCode = kbmatrixInit(&g_keyboardMatrix,
                             KEYBOARD_MCP23018_1_I2C_ADDRESS, KEYBOARD_MCP23018_2_I2C_ADDRESS,
                             KEYBOARD_SCL_PIN, KEYBOARD_SDA_PIN, 
                             KEYBOARD_INTA1_PIN, KEYBOARD_INTB1_PIN, KEYBOARD_INTA2_PIN, KEYBOARD_INTB2_PIN,
                             APP_TIMER_PRESCALER,
                             sendInputReportHandler, NULL,
                             &eraseBonds);
    APP_ERROR_CHECK(errorCode);
    initNumCapsLEDs();
    initBspLeds();
    initBatteryLevelReads();
    initBleStack();
    initScheduler();
    initDeviceManager(eraseBonds);
    initGapParams();
    initAdvertising();
    initBleServices();
    initConnectionParams();

    printf("\nBleHidKeyboard starting...\n");
    startRtcTimers();
    errorCode = ble_advertising_start(BLE_ADV_MODE_FAST);
    APP_ERROR_CHECK(errorCode);

    errorCode = kbmatrixStart(&g_keyboardMatrix);
    APP_ERROR_CHECK(errorCode);
    
    // Sleep until a new event occurs and then check the scheduler to execute any queued operations.
    while (1)
    {
        app_sched_execute();
        enterLowPowerModeAndWakeOnEvent();
    }
}

static void initUart(void)
{
    const bool noParity = false;
    uint32_t   errorCode;

    const app_uart_comm_params_t comm_params =
    {
        UART_RX_PIN,
        UART_TX_PIN,
        UART_RTS_PIN,
        UART_CTS_PIN,
        APP_UART_FLOW_CONTROL_DISABLED,
        noParity,
        UART_BAUDRATE_BAUDRATE_Baud9600
    };

    APP_UART_FIFO_INIT(&comm_params,
                       UART_RX_BUF_SIZE,
                       UART_TX_BUF_SIZE,
                       handleUartEvent,
                       APP_IRQ_PRIORITY_LOW,
                       errorCode);
    APP_ERROR_CHECK(errorCode);

    // Pull-up the Rx pin since it is usually just left floating otherwise.
    nrf_gpio_cfg_input(UART_RX_PIN, NRF_GPIO_PIN_PULLUP);
}

static void handleUartEvent(app_uart_evt_t* pEvent)
{
    if (pEvent->evt_type == APP_UART_COMMUNICATION_ERROR)
    {
        APP_ERROR_HANDLER(pEvent->data.error_communication);
    }
    else if (pEvent->evt_type == APP_UART_FIFO_ERROR)
    {
        APP_ERROR_HANDLER(pEvent->data.error_code);
    }
}

static void initRtcTimers(void)
{
    uint32_t errorCode;

    // Initialize timer module, making it use the scheduler.
    APP_TIMER_APPSH_INIT(APP_TIMER_PRESCALER, APP_TIMER_OP_QUEUE_SIZE, true);

    // Create battery timer.
    errorCode = app_timer_create(&g_batteryTimerId,
                                APP_TIMER_MODE_REPEATED,
                                handleBatteryLevelTimerEvent);
    APP_ERROR_CHECK(errorCode);

    // Create NumLock LED blink timer (also used for pass key debouncing).
    errorCode = app_timer_create(&g_blinkTimerId,
                                APP_TIMER_MODE_SINGLE_SHOT,
                                handleBlinkTimerEvent);
    APP_ERROR_CHECK(errorCode);
}

static void handleBatteryLevelTimerEvent(void* pContext)
{
    // If the last ADC sampling of Vcc is complete then update the battery level property.
    if (!nrf_adc_conversion_finished())
        return;

    uint32_t vccReading = nrf_adc_result_get();
    uint32_t batteryLevel = vccReading * 100 / 1024;
    ASSERT ( batteryLevel <= 100 );

    uint32_t errorCode = ble_bas_battery_level_update(&g_bas, batteryLevel);
    if ((errorCode != NRF_SUCCESS) &&
        (errorCode != NRF_ERROR_INVALID_STATE) &&
        (errorCode != BLE_ERROR_NO_TX_BUFFERS) &&
        (errorCode != BLE_ERROR_GATTS_SYS_ATTR_MISSING))
    {
        APP_ERROR_HANDLER(errorCode);
    }

    // Start the next ADC sample.
    nrf_adc_start();
}

static void handleBlinkTimerEvent(void* pContext)
{
    nrf_gpio_pin_clear(NUM_LOCK_PIN);

    if (g_passKeyBufferIndex >= sizeof(g_passKeyBuffer))
    {
        // The blink for the sixth and final digit has just completed so send pass key back to the central.
        g_passKeyBufferIndex = 0;
        g_waitingForPassKey = false;
        uint32_t errorCode = sd_ble_gap_auth_key_reply(g_connHandle, BLE_GAP_AUTH_KEY_TYPE_PASSKEY, g_passKeyBuffer);
        APP_ERROR_CHECK(errorCode);
    }
}

static void initNumCapsLEDs()
{
    nrf_gpio_cfg_output(CAPS_LOCK_PIN);
    nrf_gpio_cfg_output(NUM_LOCK_PIN);
    nrf_gpio_pin_clear(CAPS_LOCK_PIN);
    nrf_gpio_pin_clear(NUM_LOCK_PIN);
}

static void initBspLeds()
{
    uint32_t errorCode = bsp_init(BSP_INIT_LED,
                                  APP_TIMER_TICKS(100, APP_TIMER_PRESCALER),
                                  handleBspEvent);
    APP_ERROR_CHECK(errorCode);
}

static void handleBspEvent(bsp_event_t event)
{
    uint32_t errorCode;

    switch (event)
    {
        case BSP_EVENT_SLEEP:
            enterSleepMode();
            break;

        case BSP_EVENT_DISCONNECT:
            errorCode = sd_ble_gap_disconnect(g_connHandle, BLE_HCI_REMOTE_USER_TERMINATED_CONNECTION);
            if (errorCode != NRF_ERROR_INVALID_STATE)
            {
                APP_ERROR_CHECK(errorCode);
            }
            break;

        case BSP_EVENT_WHITELIST_OFF:
            errorCode = ble_advertising_restart_without_whitelist();
            if (errorCode != NRF_ERROR_INVALID_STATE)
            {
                APP_ERROR_CHECK(errorCode);
            }
            break;

        default:
            break;
    }
}

static void enterSleepMode(void)
{
    // Turn LEDs off to save power.
    nrf_gpio_pin_clear(CAPS_LOCK_PIN);
    nrf_gpio_pin_clear(NUM_LOCK_PIN);

    uint32_t errorCode = bsp_indication_set(BSP_INDICATE_IDLE);
    APP_ERROR_CHECK(errorCode);

    // Prepare wakeup buttons.
    errorCode = kbmatrixConfigureForWakeupOnSpacebar(&g_keyboardMatrix);
    APP_ERROR_CHECK(errorCode);
    
    // Go to system-off mode (this function will not return; wakeup will cause a reset).
    errorCode = sd_power_system_off();
    APP_ERROR_CHECK(errorCode);
}

static void initBatteryLevelReads()
{
    const nrf_adc_config_t adcConfig = { .resolution = NRF_ADC_CONFIG_RES_10BIT,
                                         .scaling = NRF_ADC_CONFIG_SCALING_SUPPLY_ONE_THIRD,
                                         .reference = NRF_ADC_CONFIG_REF_VBG };

    // Setup to sample 1/3Vcc and compare to 1.2V VBG.
    nrf_adc_configure((nrf_adc_config_t *)&adcConfig);
    nrf_adc_input_select(NRF_ADC_CONFIG_INPUT_DISABLED);

    // Start the first ADC sample so that is likely to be ready when the timer expires.
    nrf_adc_start();
}

static void initBleStack(void)
{
    uint32_t errorCode;

    // Initialize the SoftDevice handler module.
    SOFTDEVICE_HANDLER_APPSH_INIT(NRF_CLOCK_LFCLKSRC_XTAL_50_PPM, true);

    // Enable BLE stack 
    ble_enable_params_t bleEnableParams;
    memset(&bleEnableParams, 0, sizeof(bleEnableParams));
#if (defined(S130) || defined(S132))
    bleEnableParams.gatts_enable_params.attr_tab_size   = BLE_GATTS_ATTR_TAB_SIZE_DEFAULT;
#endif
    bleEnableParams.gatts_enable_params.service_changed = IS_SRVC_CHANGED_CHARACT_PRESENT;
    errorCode = sd_ble_enable(&bleEnableParams);
    APP_ERROR_CHECK(errorCode);

    // Register with the SoftDevice handler module for BLE events.
    errorCode = softdevice_ble_evt_handler_set(handleBleEvent);
    APP_ERROR_CHECK(errorCode);

    // Register with the SoftDevice handler module for BLE events.
    errorCode = softdevice_sys_evt_handler_set(handleSystemEvent);
    APP_ERROR_CHECK(errorCode);
}

static void handleBleEvent(ble_evt_t * pBleEvent)
{
    dm_ble_evt_handler(pBleEvent);
    handleBleEventForApplication(pBleEvent);
    ble_advertising_on_ble_evt(pBleEvent);
    ble_conn_params_on_ble_evt(pBleEvent);
    ble_hids_on_ble_evt(&g_hids, pBleEvent);
    ble_bas_on_ble_evt(&g_bas, pBleEvent);
}
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

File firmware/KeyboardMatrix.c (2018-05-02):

/*  Copyright (C) 2018  Adam Green (https://github.com/adamgreen)

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
    This program is distributed in the hope that it will be useful,
    but WITHOUT ANY WARRANTY; without even the implied warranty of
    MERCHANTABILITY or FITNESS FOR A PARTICULAR PURPOSE.  See the
    GNU General Public License for more details.
*/
/* KeyboardMatrix module which makes use of the I2C based MCP23018 I/O Expander to interface with the column inputs
   and row outputs of a PC matrix keyboard. */
#include <app_error.h>
#include <nrf_gpio.h>
#include <app_timer.h>
#include <string.h>
#include "KeyboardMatrix.h"
#include "KeyMappings.h"


#define COLUMN_COUNT (sizeof(g_columnMappings)/sizeof(g_columnMappings[0]))
#define SCAN_STEPS   ((COLUMN_COUNT) * 2)

// Flag bits
#define FLAG_OVERFLOW_DETECTED (1 << 0)
#define FLAG_FN_DETECTED       (1 << 1)
#define FLAG_F1_DETECTED       (1 << 2)


static void scanKeyboardMatrixCallback(void* pContext);
static void updateKeyboardInputReport(KeyboardMatrix* pThis, HidKeyboardUsageValues key);
static bool scanKeyboardForDeleteKey(KeyboardMatrix* pThis);
static bool findSpacebar(KeyboardMatrix* pThis);


uint32_t kbmatrixInit(KeyboardMatrix* pThis,
                      uint8_t i2cAddress1, uint8_t i2cAddress2, 
                      uint32_t sclPin, uint32_t sdaPin,
                      uint32_t intA1Pin, uint32_t intB1Pin, uint32_t intA2Pin, uint32_t intB2Pin,
                      uint32_t timerPrescaler,
                      keyStateCallback pCallback, void* pvContext,
                      bool* pIsDeletePressed)
{
    // We want to be able to queue up 2 writes (direction and GPIO set) + 1 read for each of the 2 MCP23018.
    const uint8_t i2cQueueSize = 2 * 3;
    
    ASSERT ( pThis );
    ASSERT ( pCallback );

    memset(pThis, 0, sizeof(*pThis));
    pThis->pCallback = pCallback;
    pThis->pvContext = pvContext;
    pThis->intA1Pin = intA1Pin;
    pThis->intB1Pin = intB1Pin;
    pThis->intA2Pin = intA2Pin;
    pThis->intB2Pin = intB2Pin;

    uint32_t errorCode = i2cInit(sclPin, sdaPin, i2cQueueSize);
    APP_ERROR_CHECK(errorCode);

    // Initialize both MCP23018 port extender devices.
    errorCode = mcp23018Init(&pThis->mcp23018_1, i2cAddress1);
    APP_ERROR_CHECK(errorCode);
    errorCode = mcp23018Init(&pThis->mcp23018_2, i2cAddress2);
    APP_ERROR_CHECK(errorCode);

    bool interruptPinMirroringDisabled = false;
    bool interruptDrainOutputDisabled = false;
    bool interruptActiveLow = false;
    bool interruptClearOnGPIORead = false;
    errorCode = mcp23018SetIoConfiguration(&pThis->mcp23018_1,
                                           interruptPinMirroringDisabled,
                                           interruptDrainOutputDisabled,
                                           interruptActiveLow,
                                           interruptClearOnGPIORead);
    APP_ERROR_CHECK(errorCode);
    errorCode = mcp23018SetIoConfiguration(&pThis->mcp23018_2,
                                           interruptPinMirroringDisabled,
                                           interruptDrainOutputDisabled,
                                           interruptActiveLow,
                                           interruptClearOnGPIORead);
    APP_ERROR_CHECK(errorCode);

    // Enable pull-up on all pins.
    errorCode = mcp23018SetGpioPullUps(&pThis->mcp23018_1, 0xFF, 0xFF);
    APP_ERROR_CHECK(errorCode);
    errorCode = mcp23018SetGpioPullUps(&pThis->mcp23018_2, 0xFF, 0xFF);
    APP_ERROR_CHECK(errorCode);

    // Check to see if Delete key is pressed during startup.
    *pIsDeletePressed = scanKeyboardForDeleteKey(pThis);

    // NOTE: APP_TIMER_TICKS results in 64-bit math.
    pThis->scanInterval = APP_TIMER_TICKS(2, timerPrescaler);

    return errorCode;
}
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

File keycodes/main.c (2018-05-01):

/*  Copyright (C) 2018  Adam Green (https://github.com/adamgreen)

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
    This program is distributed in the hope that it will be useful,
    but WITHOUT ANY WARRANTY; without even the implied warranty of
    MERCHANTABILITY or FITNESS FOR A PARTICULAR PURPOSE.  See the
    GNU General Public License for more details.
*/
// This program uses the responses I saw for each key press to generate a keyboard mapping header file.
// To find candidates for rows, I looked for pins which responded the least often. As I selected these pins to be rows,
// the pins to which they were connected were added as columns. By the 5th or so row, I had selected all of the highly 
// recurring common column pins (0, 1, 2, 3, 16, 17, 24, 25) needed by every other row pin.
#include <assert.h>
#include <math.h>
#include <stdio.h>
#include <stdint.h>
#include <stdlib.h>
#include <string.h>


typedef struct KeyStruct
{
    const char* pName;
    uint32_t    from;
    uint32_t    to;
} KeyStruct;

// I generated this table by writing code which pulled every pin low, looked for responses, and then dumped them to
// the UART. I pressed each key on the keyboard and looked at its response.
static KeyStruct g_keys[] = {
    {"HID_KEY_LEFT_CONTROL",    0x00001000, 0x01000000},
    {"HID_KEY_FN",              0x00001000, 0x00020000},
    {"HID_KEY_LEFT_GUI",        0x00000001, 0x00400000},
    {"HID_KEY_LEFT_ALT",        0x00000002, 0x00004000},
    {"HID_KEY_SPACEBAR",        0x00000008, 0x00200000},
    {"HID_KEY_RIGHT_ALT",       0x00000008, 0x00004000},
    {"HID_KEY_APP",             0x00020000, 0x00400000},
    {"HID_KEY_RIGHT_CONTROL",   0x00000004, 0x00001000},
    {"HID_KEY_LEFT_ARROW",      0x00000008, 0x00008000},
    {"HID_KEY_DOWN_ARROW",      0x00000008, 0x00080000},
    {"HID_KEY_RIGHT_ARROW",     0x00000008, 0x00100000},
    {"HID_KEY_LEFT_SHIFT",      0x00002000, 0x00010000},
    {"HID_KEY_Z",               0x00000004, 0x00000800},
    {"HID_KEY_X",               0x00000004, 0x00000400},
    {"HID_KEY_C",               0x00000004, 0x00000200},
    {"HID_KEY_V",               0x00000004, 0x00000100},
    {"HID_KEY_B",               0x00000008, 0x00000100},
    {"HID_KEY_N",               0x00000008, 0x00000080},
    {"HID_KEY_M",               0x00000004, 0x00000080},
    {"HID_KEY_COMMA",           0x00000004, 0x00000040},
    {"HID_KEY_PERIOD",          0x00000004, 0x00000020},
    {"HID_KEY_SLASH",           0x00000008, 0x00000010},
    {"HID_KEY_RIGHT_SHIFT",     0x00000004, 0x00002000},
    {"HID_KEY_UP_ARROW",        0x00000002, 0x00008000},
    {"HID_KEY_END",             0x00008000, 0x02000000},
    {"HID_KEY_CAPS_LOCK",       0x00000400, 0x00010000},
    {"HID_KEY_A",               0x00000001, 0x00000800},
    {"HID_KEY_S",               0x00000001, 0x00000400},
    {"HID_KEY_D",               0x00000001, 0x00000200},
    {"HID_KEY_F",               0x00000001, 0x00000100},
    {"HID_KEY_G",               0x00000002, 0x00000100},
    {"HID_KEY_H",               0x00000002, 0x00000080},
    {"HID_KEY_J",               0x00000001, 0x00000080},
    {"HID_KEY_K",               0x00000001, 0x00000040},
    {"HID_KEY_L",               0x00000001, 0x00000020},
    {"HID_KEY_SEMICOLON",       0x00000001, 0x00000010},
    {"HID_KEY_APOSTROPHE",      0x00000002, 0x00000010},
    {"HID_KEY_ENTER",           0x00000004, 0x00200000},
    {"HID_KEY_PAGE_DOWN",       0x00040000, 0x02000000},
    {"HID_KEY_TAB",             0x00000800, 0x00010000},
    {"HID_KEY_Q",               0x00000800, 0x00020000},
    {"HID_KEY_W",               0x00000400, 0x00020000},
    {"HID_KEY_E",               0x00000200, 0x00020000},
    {"HID_KEY_R",               0x00000100, 0x00020000},
    {"HID_KEY_T",               0x00000100, 0x00010000},
    {"HID_KEY_Y",               0x00000080, 0x00010000},
    {"HID_KEY_U",               0x00000080, 0x00020000},
    {"HID_KEY_I",               0x00000040, 0x00020000},
    {"HID_KEY_O",               0x00000020, 0x00020000},
    {"HID_KEY_P",               0x00000010, 0x00020000},
    {"HID_KEY_LEFT_BRACKET",    0x00000010, 0x00010000},
    {"HID_KEY_RIGHT_BRACKET",   0x00000040, 0x00010000},
    {"HID_KEY_BACKSLASH",       0x00000001, 0x00200000},
    {"HID_KEY_PAGE_UP",         0x00040000, 0x01000000},
    {"HID_KEY_GRAVE_ACCENT",    0x00000800, 0x01000000},
    {"HID_KEY_1",               0x00000800, 0x02000000},
    {"HID_KEY_2",               0x00000400, 0x02000000},
    {"HID_KEY_3",               0x00000200, 0x02000000},
    {"HID_KEY_4",               0x00000100, 0x02000000},
    {"HID_KEY_5",               0x00000100, 0x01000000},
    {"HID_KEY_6",               0x00000080, 0x01000000},
    {"HID_KEY_7",               0x00000080, 0x02000000},
    {"HID_KEY_8",               0x00000040, 0x02000000},
    {"HID_KEY_9",               0x00000020, 0x02000000},
    {"HID_KEY_0",               0x00000010, 0x02000000},
    {"HID_KEY_MINUS",           0x00000010, 0x01000000},
    {"HID_KEY_EQUAL",           0x00000040, 0x01000000},
    {"HID_KEY_BACKSPACE",       0x00010000, 0x00200000},
    {"HID_KEY_HOME",            0x00008000, 0x01000000},
    {"HID_KEY_ESCAPE",          0x00000002, 0x00000800},
    {"HID_KEY_F1",              0x00000400, 0x01000000},
    {"HID_KEY_F2",              0x00000200, 0x01000000},
    {"HID_KEY_F3",              0x00000200, 0x00010000},
    {"HID_KEY_F4",              0x00000002, 0x00000200},
    {"HID_KEY_F5",              0x00000002, 0x00200000},
    {"HID_KEY_F6",              0x00000002, 0x00000040},
    {"HID_KEY_F7",              0x00000020, 0x00010000},
    {"HID_KEY_F8",              0x00000020, 0x01000000},
    {"HID_KEY_F9",              0x00200000, 0x01000000},
    {"HID_KEY_F10",             0x00200000, 0x02000000},
    {"HID_KEY_F11",             0x00080000, 0x02000000},
    {"HID_KEY_F12",             0x00100000, 0x02000000},
    {"HID_KEY_PRINT_SCREEN",    0x00004000, 0x02000000},
    {"HID_KEY_INSERT",          0x00100000, 0x01000000},
    {"HID_KEY_DELETE",          0x00080000, 0x01000000}
};


#define ARRAY_SIZE(X) (sizeof(X)/sizeof(X[0]))

int compareCounts(const void* pv1, const void* pv2)
{
    uint32_t* p1 = (uint32_t*)pv1;
    uint32_t* p2 = (uint32_t*)pv2;
    uint32_t count1 = p1[1];
    uint32_t count2 = p2[1];

    if (count1 == count2)
        return 0;
    else if (count1 < count2)
        return 1;
    else
        return -1;
}

int main(void)
{
    static const char filename[] = "../firmware/KeyMappings.h";
    FILE* pFile = fopen(filename, "w");
    if (!pFile)
    {
        printf("error: Failed to open %s for writing\n", filename);
        return 1;
    }
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

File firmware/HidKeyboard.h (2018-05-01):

/*  Copyright (C) 2018  Adam Green (https://github.com/adamgreen)

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
    This program is distributed in the hope that it will be useful,
    but WITHOUT ANY WARRANTY; without even the implied warranty of
    MERCHANTABILITY or FITNESS FOR A PARTICULAR PURPOSE.  See the
    GNU General Public License for more details.
*/
// HID Keyboard Definitions
#ifndef HID_KEYBOARD_H_
#define HID_KEYBOARD_H_

// Keyboard/Keypad HID Usage Values.
typedef enum HidKeyboardUsageValues
{
    HID_KEY_NOEVENT = 0x00,
    HID_KEY_ERROR_ROLLOVER = 0x01,
    HID_KEY_POST_FAIL = 0x02,
    HID_KEY_ERROR_UNDEFIEND = 0x03,
    HID_KEY_A = 0x04,
    HID_KEY_B,
    HID_KEY_C,
    HID_KEY_D,
    HID_KEY_E,
    HID_KEY_F,
    HID_KEY_G,
    HID_KEY_H,
    HID_KEY_I,
    HID_KEY_J,
    HID_KEY_K,
    HID_KEY_L,
    HID_KEY_M,
    HID_KEY_N,
    HID_KEY_O,
    HID_KEY_P,
    HID_KEY_Q,
    HID_KEY_R,
    HID_KEY_S,
    HID_KEY_T,
    HID_KEY_U,
    HID_KEY_V,
    HID_KEY_W,
    HID_KEY_X,
    HID_KEY_Y,
    HID_KEY_Z,
    HID_KEY_1 = 0x1E,
    HID_KEY_2,
    HID_KEY_3,
    HID_KEY_4,
    HID_KEY_5,
    HID_KEY_6,
    HID_KEY_7,
    HID_KEY_8,
    HID_KEY_9,
    HID_KEY_0,
    HID_KEY_ENTER = 0x28,
    HID_KEY_ESCAPE = 0x29,
    HID_KEY_BACKSPACE = 0x2A,
    HID_KEY_TAB = 0x2B,
    HID_KEY_SPACEBAR = 0x2C,
    HID_KEY_MINUS = 0x2D,
    HID_KEY_EQUAL = 0x2E,
    HID_KEY_LEFT_BRACKET = 0x2F,
    HID_KEY_RIGHT_BRACKET = 0x30,
    HID_KEY_BACKSLASH = 0x31,
    HID_KEY_SEMICOLON = 0x33,
    HID_KEY_APOSTROPHE = 0x34,
    HID_KEY_GRAVE_ACCENT = 0x35,
    HID_KEY_COMMA = 0x36,
    HID_KEY_PERIOD = 0x37,
    HID_KEY_SLASH = 0x38,
    HID_KEY_CAPS_LOCK = 0x39,
    HID_KEY_F1 = 0x3A,
    HID_KEY_F2,
    HID_KEY_F3,
    HID_KEY_F4,
    HID_KEY_F5,
    HID_KEY_F6,
    HID_KEY_F7,
    HID_KEY_F8,
    HID_KEY_F9,
    HID_KEY_F10,
    HID_KEY_F11,
    HID_KEY_F12,
    HID_KEY_PRINT_SCREEN = 0x46,
    HID_KEY_SCROLL_LOCK = 0x47,
    HID_KEY_PAUSE = 0x48,
    HID_KEY_INSERT = 0x49,
    HID_KEY_HOME = 0x4A,
    HID_KEY_PAGE_UP = 0x4B,
    HID_KEY_DELETE = 0x4C,
    HID_KEY_END = 0x4D,
    HID_KEY_PAGE_DOWN = 0x4E,
    HID_KEY_RIGHT_ARROW = 0x4F,
    HID_KEY_LEFT_ARROW = 0x50,
    HID_KEY_DOWN_ARROW = 0x51,
    HID_KEY_UP_ARROW = 0x52,
    HID_KEYPAD_NUM_LOCK = 0x53,
    HID_KEYPAD_SLASH = 0x54,
    HID_KEYPAD_ASTERISK = 0x55,
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

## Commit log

2017-11-24 Initial commit
    I am starting from some code that I wrote previously which interfaces
    to an old AT style keyboard and exposes it as a BLE HID wireless
    keyboard.
    Future commits will change it to interface directly to the keyboard
    matrix in a modern keyboard, replacing the existing USB electronics.
2017-11-27 Initial MCP23018 I/O expander driver
    I also hacked some code into main.c to verify basic functionality of
    the I/O expander when connected to a single column of 2 row of
    switches.
2017-11-28 Handle NULL pointers in mcp23018AsyncGetGpio()
    Previously the pPortA and pPortB parameters had to be non-NULL or a
    crash would occur in the gpioReadCompletedCallback() when it attempted
    to write the resulting read data.
    [MCP23018.c]
2017-11-29 Now sends 'a' and ' ' over BLE
    Pressing the button on the first row will now send an 'a' key press to
    my iOS device via BLE. Pressing the button on the second row sends a
    space.
2017-11-29 Remove AT keyboard code
    This commit removes the AT keyboard intefacing code that I used for
    the original prototype now that I have the basics of the keyboard
    matrix version built. I previously kept it around to quickly lookup
    how I did things for that version.
2018-01-03 Switch keyboard scanning timer to single shot
    Previously the timer used for scanning the keyboard matrix was setup to
    be repeating but this caused problems when the main loop was executing
    long running tasks when too many of these timer events would fill up
    the application scheduling queue. The timer is now single shot and is
    restarted each time the main loop finally gets around to running the
    callback for the previous timer tick. This will add more jitter to the
    sample times but that doesn't matter for keyboard scanning anyway.
    [KeyboardMatrix.c]
2018-01-08 Add wakeup on spacebar press
    Added kbmatrixConfigureForWakeupOnSpacebar() function which configures
    the row and column pins corresponding to the space key. The column to
    which the space key is connected is pulled low and the row to which it
    is attached is setup to pull the interrupt pin on the MCP23018 low
    when the space key closes the circuit. The MCP23018 interrupt pin is
    configured as a wakeup source for the nRF51 CPU.
2018-03-03 Initial commit of schematic
    [BleHidKeyboard.sch]
2018-03-03 Adding documents
    These are documents related to the hardware devices used in the
    keyboard circuit.
2018-03-03 Update schematic to pass ERC
    [BleHidKeyboard.sch]
2018-03-15 Version 1 of PCB layout
    This is the version that I sent to OSHPark to have manufactured on
    3/14/2018.
    [BleHidKeyboard.brd, BleHidKeyboard.sch]
2018-05-01 Firmware sending first key presses from real key presses
    I now have PCBs soldered up with the keyboard mylar connected. This
    firmware is able to process presses on this keyboard and send them
    to my iPhone via BLE. It is missing some stuff like caps/numlock LED,
    sleep support, etc that will be added in future commits.
    This commit includes:
    * keycodes/main.c which I build with a simple "gcc main.c". When run it
    generates the mapping of column/row contact closures to HID usage
    values. This is based on the data that I gathered as I pressed each
    key on the keyboard and recorded which pins were shorted in response.
    This program generated the KeyMappings.h included in this commit.
    * Create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
    [HidKeyboard.h, KeyboardMatrix.c, custom_board.h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]
2018-05-01 Change IO direction and pull GPIO pin low in one async op
    Previously the IO direction was changed synchronously from within the
    timer intterupt and then the GPIO async write was started. Now they
    are both done asynchronously through a new function added to the
    MPC23018 module.
    I now malloc the I2C transaction queue dynamically since the required
    size really depends on how many MCP23018 objects you have and how you
    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
2018-05-01 Added Caps & Num Lock support
    Now processes the HID output reports to determine the PC's num & caps
    lock state and use them to update the corresponding LEDs on my PCB.
2018-05-01 Put nRF51 to sleep if FN + F1 (Sleep) key is pressed
    Make sure to turn caps & num lock LED off before putting device to
    sleep.
2018-05-01 Keyboard now wakes up on spacebar press
    Added code which figures out the column and row for the space bar in
    the current key mapping. Uses this information to pull that column low
    and configure that row pin to generate an interrupt if pulled low
    before entering sleep.
2018-05-01 Erase BLE bonding information if Delete pressed on startup
    kbmatrixInit() now checks to see if the Delete key is pressed during
    initialization. This can be used to erase the BLE pairing bonds.
    I pulled the timer startup code out of the init path and put it in
    kbmatrixStart() since starting the timers before BLE caused errors.
    [KeyboardMatrix.c, main.c]
2018-05-02 Was always detecting Delete pressed on startup
    I was waiting for the wrong async operation to complete in
    scanKeyboardForDeleteKey(). I should have been waiting for the get to
    finish but I was waiting on the set instead.
    I also made a similar change in scanKeyboardMatrixCallback().
    [KeyboardMatrix.c]
2018-05-02 Don't need to connect as often as we were
    My maximum typing rate target is about 16Hz so I used that as a guide
    to how long the minimum and maximum connection interval should be.
    This helps reduce the average current usage by ~100uA.
2018-05-02 Switch to 1.2k LED current limiting resistors
    This reduces current usage by half but still leaves them bright enough
    to see.
    [BleHidKeyboard.brd, BleHidKeyboard.sch]
2018-05-02 Send back actual battery level
    Now uses the ADC to sample the voltage of the battery instead of using
    a simulator to fake values to send back via the BLE battery service.
    It is quite cool that the ADC in the nRF51 can do this without using
    any external pins/connections. Internally it is able to compare 1/3Vcc
    to a 1.2VBG.
    Other updates include:
    * No longer debug dump the HID output report to the UART.
    * Renamed the keyboard in the advertising data.
    * Sample the battery every minute.
    [main.c]
2018-05-07 Version 3 of the PCB design
    This is the design being sent off to OSHPark on May 6th, 2018.
    This version of the PCB no longer uses the 20-pin Molex connector on
    the bottom of the Dynastream N5150M5CD module and instead uses the
    pads around the perimeter of the N5150M4CD module (actually the same
    module but without the Molex and SWD connectors) instead. The module
    will now mount on the bottom of the PCB with the module can sticking up
    through a hole in this new PCB. This will give us extra height
    clearance and correct the problem that the current PCB doesn't fit in
    the original keyboard case.
    I updated the firmware to accomodate the change in pin mappings for
    UART, I2C, LEDs, etc.
    [BleHidKeyboard.brd, BleHidKeyboard.sch]
2018-05-07 Add schematic/PCB images
2018-05-07 Add PCB and schematic to README
2018-05-07 Fix some text alignment issues in schematic
    I changed the UI options to only use vectored fonts and that broke a
    few things in the schematic.
    [BleHidKeyboard.sch]
2018-05-07 Add photos of keyboard w/ original PCB
2018-05-07 Add photo w/ version 1 PCB in keyboard
    This version of the PCB doesn't work in the keyboard since the module
    sticks up too high and interferes with keyboard membrane. Version 3
    fixes that problem.
2018-06-03 Switch from QWERTY to ABC keyboard layout
    Can set KEYBOARD_ABC to 0 in KeyMappings.h to switch back to QWERTY
    layout.
2018-06-07 Enable MITM 6-digit passkey pairing
    Changes include:
    * Many of the GATT attributes are now marked to use encryption with
    MITM (Man In The Middle) protection enabled.
    * MITM protection is enabled when enabling the device manager. The
    BLE_GAP_IO_CAPS_KEYBOARD_ONLY bit is set to indicate that this device
    only has a keyboard and no display. This forces the central device to
    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
2019-02-23 Add labels for back of keyboard
    I created two labels that I could print out and place on the back of
    the keyboard.
    * A diagram showing how the batteries are to be inserted.
    * Notes about special keypresses and meaning of Scroll Lock LED.

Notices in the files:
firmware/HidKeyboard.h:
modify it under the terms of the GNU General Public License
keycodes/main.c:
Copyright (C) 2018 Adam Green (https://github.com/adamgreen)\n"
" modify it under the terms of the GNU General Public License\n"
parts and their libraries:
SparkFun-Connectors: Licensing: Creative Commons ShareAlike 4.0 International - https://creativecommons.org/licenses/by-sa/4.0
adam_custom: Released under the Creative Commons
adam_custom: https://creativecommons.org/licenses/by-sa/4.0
